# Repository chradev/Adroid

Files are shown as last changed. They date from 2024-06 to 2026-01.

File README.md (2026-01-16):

## Adroid

<a href="https://github.com/chradev/Adroid" target="_blank">Adroid</a> is proposed as an open S.T.E.A.M. platform and a process for building educational aids like robots following the Open Source movement in all its aspects, including but not limited to the ideas, algorithms, internal and external design, mechanical, electronic, and software staff. It is intended to include latest science, technology, and art achievements with a special respect to ***"Do it by mind, heart, and hands; learn by doing and teach by learning!"*** principles or simply ***"Learn by Doing!"***, appropriate for any person's age, interests, and profession.

Adroid robots ­ the Small, the Tall, the Wide, the Smart Малкият, Високият, Широкият, Умният (Дребосъкът, Дангалакът, Дебелакът, Добрякът)

#### <p align=center>Adroid the project, is all about "Do it by mind, heart, and hands; learn by doing and teach by learning!"<br>whose mission is to perfect your brain and hands using the latest science, technology, and art achievements.</p>

Adroid is not only a platform but it is also a continuous process intended to accumulate all gained knowledge and experience by all participants in S.T.E.A.M. the educational processes using it. A special relational multi-dimensional knowledge base and tools will be created and updated continuously to help the learning and teaching processes. On the other hand Adroid can be used by artists, scientists and engineers to reach better results faster.

## Learn by Doing!

Open S.T.E.A.M. is an idea directly related to a platform for multidisciplinary projects, the scope of which is the best possible learning process through the active participation of the parties in their implementation. In this line of thought, the parties to whom the process is directed are equal in terms of rights and obligations, often changing their roles as students and teachers.

Therefore, the following topics are outlined in the Adroid project as a beginning:

* Development of AI-based open S.T.E.A.M. process and comprehensive toolkit to learn and teach by doing;
* Stereo and panoramic robot vision, including AI-based object detection, recognition and following;
* Speech synthesis and recognition for human-like communicating robots, optionally based on AI;
* Emotional behavior through animation on the built-in robot display optionally based on AI;
* Active Ball Joint Mechanism incl. 3D absolute positioning system for head movement;
* Distributed, multi-process/-core/-thread control system based on uROS and ROS 2;
* Advanced stereo and panoramic system for streaming with low latency and ePTZ;
* Body transformation based on a set of strength and positioning sensors;
* Development of liquid multi-color jet system for painting robots;
* Following the latest achievements in the sciences and technologies, etc.

The above list will be updated continuously, so any new ideas are welcome.

## How easy is it to use AI?

#### It is easy to use Raspberry Pi AI Kit (HAILO 8L - 13 TOPS) on Raspberry Pi 5!

Some tests were made to use the Raspberry Pi AI Kit (HAILO 8L - 13 TOPS) on Raspberry Pi 5 16GB with Debian 13 (Trixie) desktop distribution and Linux kernel ver. 6.12.47. AI Kit's M.2 module and 512GB NVMe SSD were mounted on WaveShare PCIe to 2-CHANNEL M.2 HAT+ for Raspberry Pi 5. Arducam 16MP IMX519 autofocus camera was connected to the first CSI interface, and appropriate software (libcamera2, OpenCV etc.) was installed and tested to work. A series of performance tests were also made, and a better Geekbench CPU score was found for Raspberry Pi 5 Model B Rev 1.1 vs. Rev 1.0 (<a href="https://browser.geekbench.com/v6/cpu/15497913" target="_blank">2091/891</a> vs. <a href="https://browser.geekbench.com/v6/cpu/5636316" target="_blank">1629/793</a>).

Appropriate software and AI demo examples for the Raspberry Pi AI Kit (HAILO 8L - 13 TOPS) are installed and tested to work. The camera was directed to the high-resolution monitor of the desktop computer, where the following YouTube video clips were displayed:

* <a href="https://www.youtube.com/watch?v=w_agSeXwxhU" target="_blank">Kara Swisher's discussion with Nobel laureate Geoffrey Hinton, known as one of the “godfathers of AI” for his work</a>,
* <a href="https://www.youtube.com/watch?v=VX-Vx-aLdHg" target="_blank">National Folklore Festival for amateurs "U bre, de bre", Varna, Bulgaria, 2013 - doubles competition, second round</a>.

<table style="width: 100%; height: 100%; margins: 0; padding: 0;">
  <tr style="margins: 0; padding: 0;">
    <td style="width: 20%; height: 100%; margins: 0; padding: 0;">
      </td>
    <td style="width: 20%; height: 100%; margins: 0; padding: 0;">
      </td>
    <td style="width: 30%; height: 100%; margins: 0; padding: 0;">
      </td>
    <td style="width: 30%; height: 100%; margins: 0; padding: 0;">
      </td>
  </tr>
</table>

It is worth noting that when using the Raspberry Pi AI Kit (HAILO 8L - 13 TOPS), the CPU load (16% total and 11.5% for the AI application) and memory usage (1.34 GB total and 233 MB for the AI application) of the Raspberry Pi 5 are negligible. On the other hand, video captured by the Arducam 16MP IMX519 autofocus camera was processed by the Raspberry Pi AI Kit (HAILO 8L - 13 TOPS) with the same frame rate and with a lot of objects analyzed.

#### It is easy to use Raspberry Pi AI Camera – IMX500 12MP on Raspberry Pi 5!

The Raspberry Pi 12MP AI Camera (IMX500) module was installed on the second CSI interface of the same Raspberry Pi 5 16GB, appropriate configuration was set and it was tested to work. After installing of required software AI functionality was tested with the above mentioned video clips.

<table style="width: 100%; height: 100%; margins: 0; padding: 0;">
  <tr style="margins: 0; padding: 0;">
    <td style="width: 19%; height: 100%; margins: 0; padding: 0;">
      </td>
    <td style="width: 15.4%; height: 100%; margins: 0; padding: 0;">
      </td>
    <td style="width: 24%; height: 100%; margins: 0; padding: 0;">
      </td>
    <td style="width: 24%; height: 100%; margins: 0; padding: 0;">
      </td>
  </tr>
</table>

#### AI solutions comparison

Later on both Raspberry Pi AI Camera – IMX500 12MP and Raspberry Pi AI Kit (HAILO 8L - 13 TOPS) with Arducam 16MP IMX519 autofocus camera were tested to work together on Raspberry Pi 5 16GB.

<table style="width: 100%; height: 100%; margins: 0; padding: 0;">
  <tr style="margins: 0; padding: 0;">
    <td style="width: 8.5%; height: 100%; margins: 0; padding: 0;">
      </td>
    <td style="width: 18%; height: 100%; margins: 0; padding: 0;">
      </td>
    <td style="width: 19.5%; height: 100%; margins: 0; padding: 0;">
      </td>
    <td style="width: 31%; height: 100%; margins: 0; padding: 0;">
      </td>
  </tr>
</table>

Measured total CPU load was 26% (2.5% and 10.4%, respectively), and total memory usage was 10% or 1.58 GB (316 MB and 230 MB, respectively). As a result of comparison, it can be noted that the RPi AI camera solution is 30% cheaper (84.36 € vs. 85.90 € + 33.75 €) and uses fewer CPU resources (2.5% vs. 10%), but using a standard RPi camera with a HAILO 8L AI accelerator is a more powerful and unified solution. Moreover, the use of dedicated AI processing units will allow for easier migration to other, much more powerful platforms.

#### HAILO AI development software

<a href="https://hailo.ai/" target=_blank>Hailo AI</a> development software and examples were installed on Raspberry Pi 5 16GB with Seeed Studio's PCIe 3.0 to 2x M.2 hat and tested with Raspberry Pi AI Kit (HAILO 8L - 13 TOPS) thanks to the following projects:

- <a href="https://github.com/hailo-ai/hailo-apps" target=_blank>Hailo Applications</a>
- <a href="https://github.com/hailo-ai/hailo-rpi5-examples" target=_blank>Hailo Raspberry Pi 5 Examples</a>

After fixing the installation problem by changing the `HAILORT_PACKAGE_NAME_RPI` global variable in <a href="https://github.com/hailo-ai/hailo-apps/blob/main/hailo_apps/python/core/common/defines.py#L15" target=_blank>defines.py</a> to `hailort` all staff started working fine, and the following results were observed:

<table style="width: 100%; height: 100%; margins: 0; padding: 0;">
  <tr style="margins: 0; padding: 0;">
    <td style="width: 33.3%; text-align: center; margins: 0; padding: 0;">
      <p>Object detection: hailo-detect-simple</p></td>
    <td style="width: 33.3%; text-align: center; margins: 0; padding: 0;">
      <p>Pose estimation: hailo-pose</p></td>
    <td style="width: 33.3%; text-align: center; margins: 0; padding: 0;">
      <p>Instance segmentation: hailo-seg</p></td>
  </tr>
  <tr style="margins: 0; padding: 0;">
    <td style="text-align: center; margins: 0; padding: 0;">
      </td>
    <td style="text-align: center; margins: 0; padding: 0;">
      </td>
    <td style="text-align: center; margins: 0; padding: 0;">
      </td>
  </tr>
</table>

**Notes:**

- Animated pictures are taken from <a href="https://github.com/hailo-ai/hailo-apps" target=_blank>Hailo Applications</a>. Thanks for sharing.
- Task charts are taken from <a href="https://hailo.ai/products/hailo-software/model-explorer-vision/" target=_blank>Hailo Model Explorer</a> for HAILO 8L AI processor, All Models, Original + Quantized and Batch size = 8;

#### Performance comparison table of tested AI solutions

It was chosen to test the Raspberry Pi 5 Model B with 16 GB and an adapter with 2x M.2 PCIe slots for connecting both the NVMe SSD disk and the HAILO 8L AI co-processor. There were two candidates with PCIe switches: Gen 2 from Waveshare and Gen 3 from Seed Studio. One of the limitations is that RPi 5 PCIe Gen 3 support is experimental, and some problems encountered at installation had to be overcome by adding `dtoverlay=pciex1-compat-pi5,no-mip` in `/boot/firmware/config.txt`. Linux commands like `hdparam` and `dd`, and <a href="https://github.com/Seeed-Projects/Benchmarking-YOLOv8-on-Raspberry-PI-reComputer-r1000-and-AIkit-Hailo-8L" target=_blank>performance tests developed by the Seeed Studio team</a> were used to measure NVMe SSD read/write speeds and HAILO 8L performance at processing object detection and pose estimation models. The results are summarized in the table below:



**Notes:**

- Using a PCIe Gen 3 switch is a must to increase:
 - the speeds of both write and buffered read operations for NVMe SSD disks,
 - performance of Hailo AI accelerator modules at video streams processing;
- Seeed Studio's PCIe 3.0 to 2x M.2 hat is a good choice because:
 - it doubles R/W speeds over PCIe to NVMe SSD and Hailo AI modules,
 - it keeps the GPIO header usable with its rear-mount design,
 - it doesn't matter where the two devices are plugged in;
- Unfortunately,
 - Gen 3 speeds is "out of spec" and officially unsupported by Raspberry Pi,
 - it has a problem with M.2 Interface Peripheral (MIP) compatibility on RPi 5, 
 - it is more expensive because of its over-functionality and lack of alternatives.

#### Benchmark of YOLOv8 AI models made by Seeed Studio team

YOLOv8 (You Only Look Once version 8) is the popular most YOLO series of real-time pose estimation and object detection models. It builds upon the strengths of its predecessors by introducing several advancements in speed, accuracy, and flexibility. The Raspberry AI kit, featuring a 13 TOPS neural network inference accelerator built around the Hailo-8L chip is used to accelerate inference speed of RPi 5 and CM4 boards. PCIe Gen 2 and Gen 3 speeds are used to measure performance. In addition main CPU and the NVIDIA Jetson Orin NX 16GB with built-in accelerator are also used to test the same demo. Results are published on:

* <a href="https://github.com/Seeed-Projects/Benchmarking-YOLOv8-on-Raspberry-PI-reComputer-r1000-and-AIkit-Hailo-8L" target="_blank">Github project: Benchmarking-YOLOv8-on-Raspberry-PI-reComputer-r1000-and-AIkit-Hailo-8L</a>,
* <a href="https://wiki.seeedstudio.com/benchmark_on_rpi5_and_cm4_running_yolov8s_with_rpi_ai_kit/" target="_blank">Seeed Studio wiki: Benchmark on RPi5 and CM4 running yolov8s with rpi ai kit </a>.

<table style="width: 100%; height: 100%; margins: 0; padding: 0;">
  <tr style="margins: 0; padding: 0;">
    <td style="width: 22%; height: 100%; margins: 0; padding: 0;">
      </td>
    <td style="width: 26%; height: 100%; margins: 0; padding: 0;">
      </td>
    <td style="width: 26%; height: 100%; margins: 0; padding: 0;">
      </td>
    <td style="width: 26%; height: 100%; margins: 0; padding: 0;">
      </td>
  </tr>
</table>

**Notes:**

- The acceleration effect of Hailo is noticeable;
- The frame rate of Pi5 under PCIe Gen3 is twice as high as under PCIe Gen2;
- The performance of CM4 after acceleration is unexpectedly good;
- The power consumption performance of Pi5 and CM4 is excellent when accelerated by Hailo8L.

#### Comparison table of AI solutions from different manufacturors



**Note:** The prices are taken from <a href="https://erelement.com/" target="_blank">Erelement Bg - Electronics and robotics</a>.

## Adroid robots comparison tables

#### Adroid robot variants

<table style="overflow-y: hidden; width: 100%;height: 100%;font-size:0.9em;text-align: center; border:1px; border-collapse: collapse;">
<thead>
<tr >
    <th width="10%" style="text-align: center;" > Adroid robot <br> variant / feature </th>
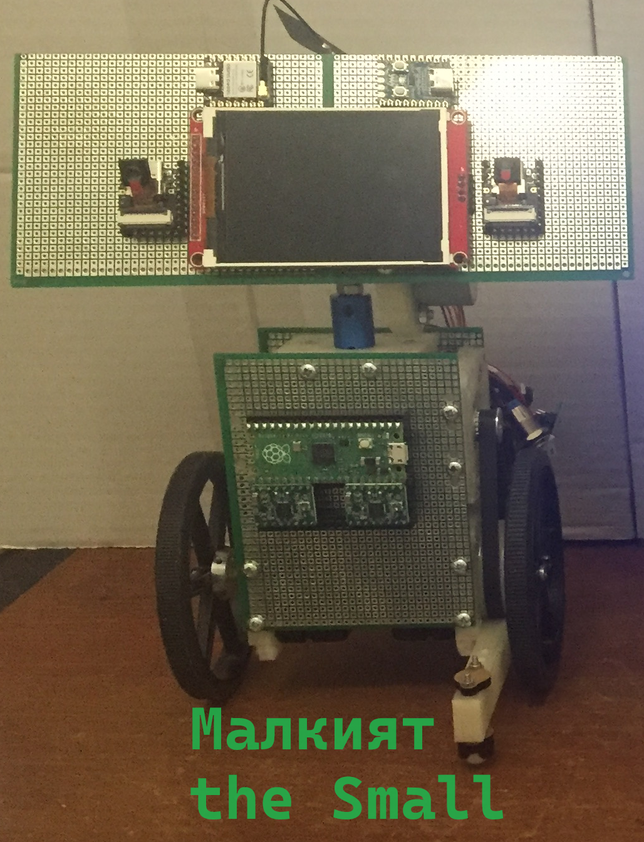
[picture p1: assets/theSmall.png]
    <th width="18%" style="text-align: center;"> </th>
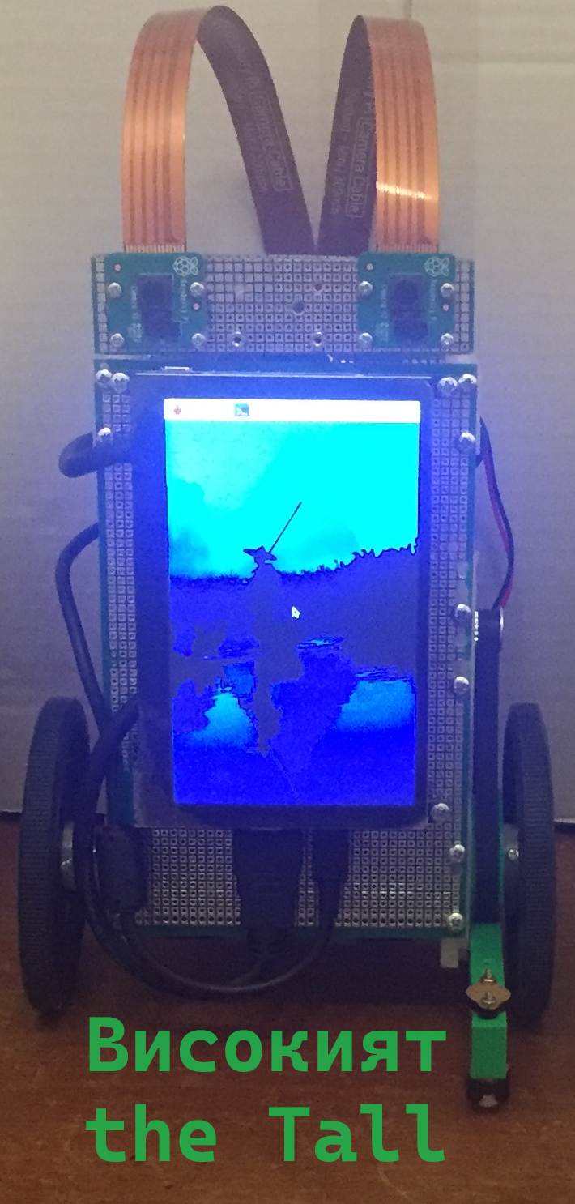
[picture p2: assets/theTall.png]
    <th width="18%" style="text-align: center;"> </th>
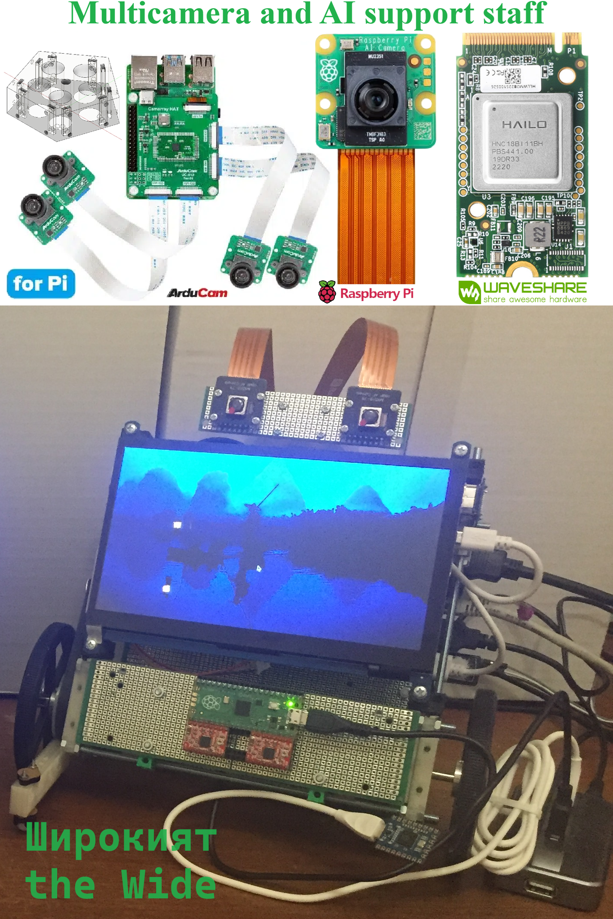
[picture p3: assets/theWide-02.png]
    <th width="18%" style="text-align: center;"> </th>
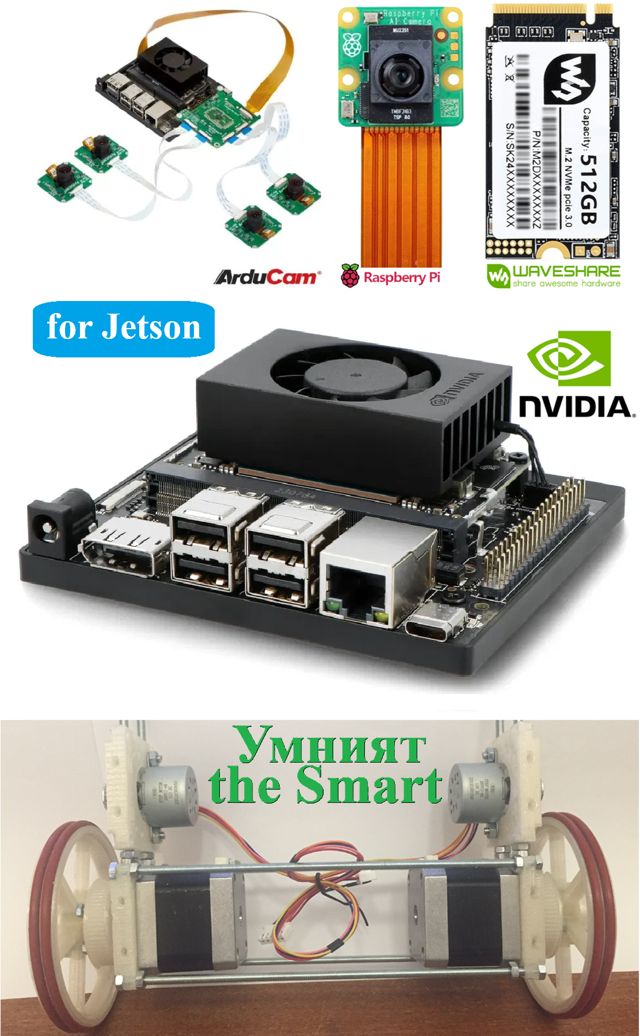
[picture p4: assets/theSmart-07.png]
    <th width="18%" style="text-align: center;"> </th></tr>
</thead><tbody>
<tr >
    <td style="text-align: end;"> Pricing </td>
    <td style="text-align: center;"> Low budget variant </td>
    <td style="text-align: center;" colspan="2" style="text-align: center;"> Advanced variants </td>
    <td style="text-align: center;">Variant with built-in AI acceleration</td></tr>
<tr style="background-color: #fcfccc;">
    <td style="text-align: end;" > Main computer hardware </td>
    <td style="text-align: center;" > Seeed Studio XIAO ESP32S3 Sense module </td>
    <td style="text-align: center;" colspan="2" > RPi 5 4/8/16GB RAM SBC, active cooling, Gen 2/3 PCIe to 2x M.2 hat, up to 2x NVMe SSD, Hailo 8/8L or other AI M.2 accelerator module (optional) </td>
    <td style="text-align: center;" >Nvidia Jetson Orin Nano Super Dev Kit, Gen 3 NVMe SSD</td></tr>
<tr >
    <td style="text-align: end;" > Main computer software </td>
    <td style="text-align: center;" > Free RTOS, C/C++ </td>
    <td style="text-align: center;" colspan="3" > Linux, C/C++, Python, JavaScript </td></tr>
<tr style="background-color: #fcfccc;">
    <td style="text-align: end;" > Dispaly devices </td>
    <td style="text-align: center;" > 3.2" TFT SPI or 4-5" TFT HDMI display and RPi Pico module </td>
    <td style="text-align: center;" colspan="2" > 5-7" TFT HDMI display or multimedia projector </td>
    <td style="text-align: center;" > 7" TFT DisplayPort display or multimedia projector </td></tr>
<tr >
    <td style="text-align: end;" > Auxiliary computer hardware </td>
    <td style="text-align: center;" colspan="4" > RPi Pico module </td></tr>
<tr style="background-color: #fcfccc;">
    <td style="text-align: end;" > Auxiliary computer software </td>
    <td style="text-align: center;" colspan="4" > C/C++, RPi Pico multicore and PIO features </td></tr>
<tr >
    <td style="text-align: end;" > Vision hardware </td>
    <td style="text-align: center;" > 1-2x Seeed Studio XIAO ESP32S3 Sense module with 2&nbsp;MP OV2640 SPI camera </td>
    <td style="text-align: center;" colspan="3" > 1-8x RPi or Arducam 8, 16 or 64 MP CSI cameras connected to RPi&nbsp;5 directly or via Arducam CamArray Hat, RPi AI cameras (optional) </td></tr>
<tr style="background-color: #fcfccc;">
    <td style="text-align: end;" > Vision software </td>
    <td style="text-align: center;" > Free RTOS, C/C++ and WS based MJPEG streaming </td>
    <td style="text-align: center;" colspan="3" > Linux, C/C++, Python, WS based h264 streaming server </td></tr>
<tr >
    <td style="text-align: end;" > Sound system </td>
    <td style="text-align: center;" > External sound card and built-in camera microphones </td>
    <td style="text-align: center;" colspan="2" > Speakers connected to HDMI display or I2S and microphones controlled by RPi 5 </td>
    <td style="text-align: center;" >I2S, sound amplifier and speakers</td></tr>
<tr style="background-color: #fcfccc;">
    <td style="text-align: end;" > Vision PTZ and head control </td>
    <td style="text-align: center;" >  Auxiliary computer with 1-2x geared stepper motors and position sensors </td>
    <td style="text-align: center;" colspan="3" > Auxiliary computer with 1-4x geared stepper motors, optional active ball joint mechanism, 3D position sensors and ePTZ based on camera control </td></tr>
<tr >
    <td style="text-align: end;" > Body slope control </td>
    <td style="text-align: center;" colspan="4" >  Auxiliary computer with 1-2x geared stepper motors and strength and position sensors </td></tr>
<tr style="background-color: #fcfccc;">
    <td style="text-align: end;" > Main movement control </td>
    <td style="text-align: center;" colspan="4" >  Auxiliary computer with 2x stepper motors and distance, line following, edge etc. sensors </td></tr>
<tr >
    <td style="text-align: end;" > Painting system </td>
    <td style="text-align: center;" > Single pen system </td>
    <td style="text-align: center;" colspan="3" > Multiple-pen or liquid multicolor jet system </td></tr>
<tr style="background-color: #fcfccc;">
    <td style="text-align: end;" > Power consumption </td>
    <td style="text-align: center;" > 10W max; 2S LiPo battery</td>
    <td style="text-align: center;" colspan="3" > 25W max; 3S LiPo battery</td></tr>
<tr style="background-color: #fcfccc;">
    <td style="text-align: end;" > Power control </td>
    <td style="text-align: center;" colspan="4" > Wireless charger and UPS like power control </td></tr>
</tbody></table>

#### Adroid robot main computer variants

<table style="overflow-y: hidden; width: 100%;font-size:0.9em;text-align: center; border:1px; border-collapse: collapse;">
<thead><tr >
<th width="10%" style="text-align: center;vertical-align: middle;" > Adroid robot <br> main computer <br> variant / feature </th>
<th width="18%" style="text-align: center;vertical-align: top;"> Seeed Studio XIAO ESP32S3 <br> (Multiply MCUs & FreeRTOS) <br>
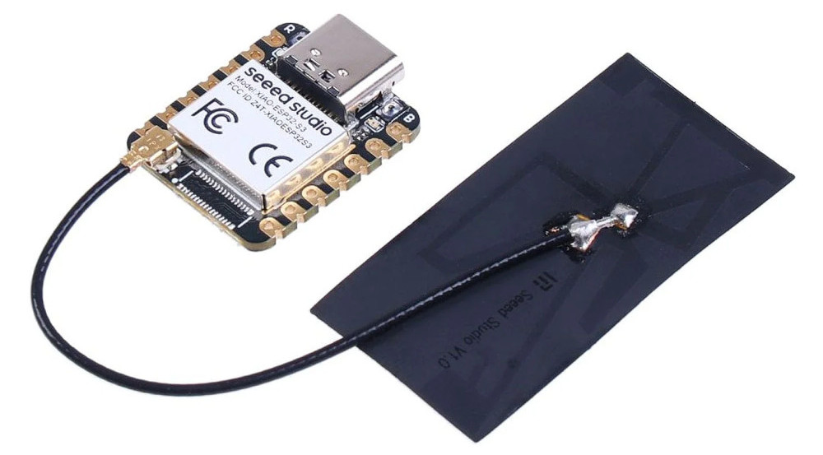
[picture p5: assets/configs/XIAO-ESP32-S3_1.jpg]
                                              <br> 
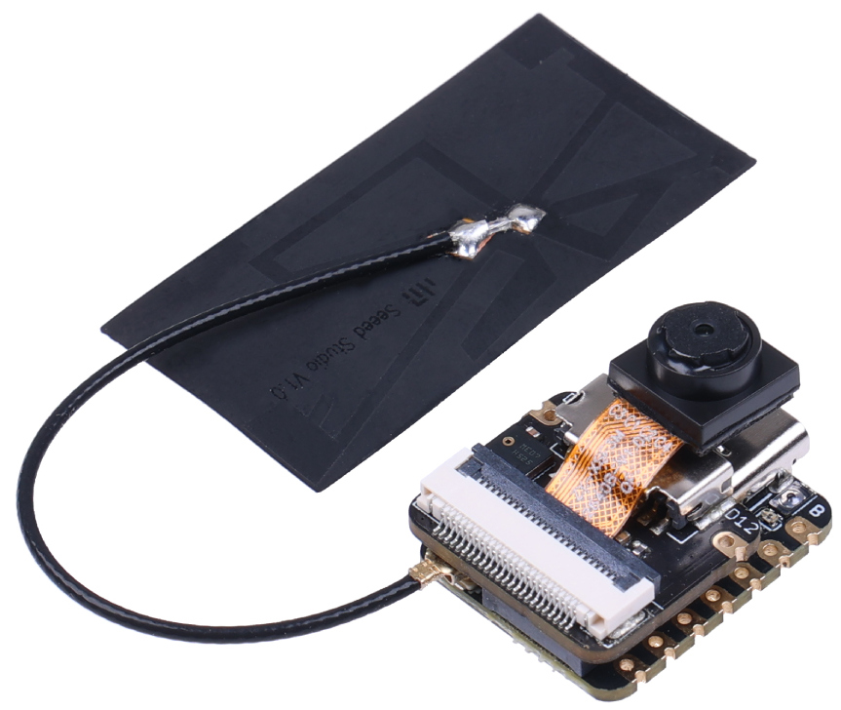
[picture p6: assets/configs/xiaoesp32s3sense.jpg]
                                              <br>
                                             2x Seeed Studio XIAO ESP32S3 Sense with OV2640 SPI camera and microphone<br> 
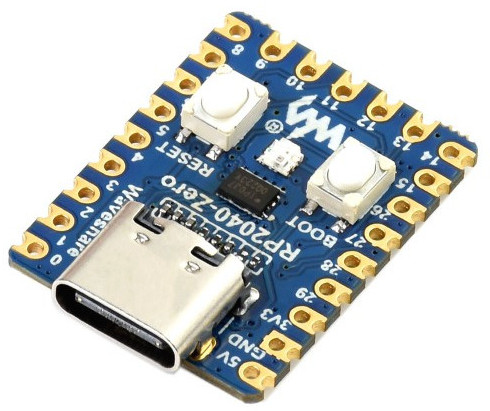
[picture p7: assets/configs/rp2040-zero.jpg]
                                             
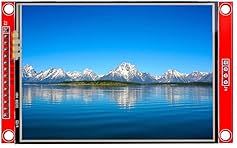
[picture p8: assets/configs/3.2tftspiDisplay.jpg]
                                              <br>
                                             RP2040-Zero and 3.2" TFT 320x240 SPI  built-in display (simple option)<br>
                                             
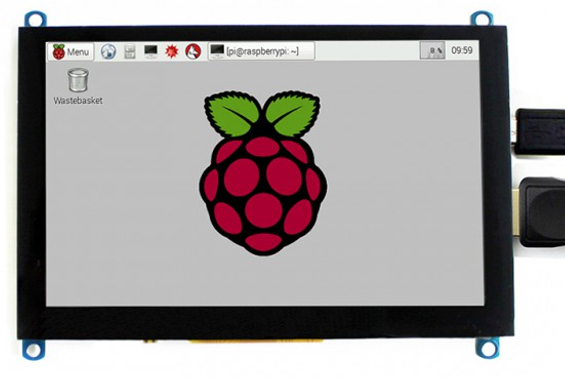
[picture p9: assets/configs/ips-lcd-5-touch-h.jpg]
                                              <br>
                                             RP2040-Zero and 5" TFT 800/480 HDMI  built-in display (advanced option)<br>
                                             </th>
<th width="18%" style="text-align: center;vertical-align: top;"> Raspberry Pi Zero 2 W <br> (Single SBC & Linux) <br>
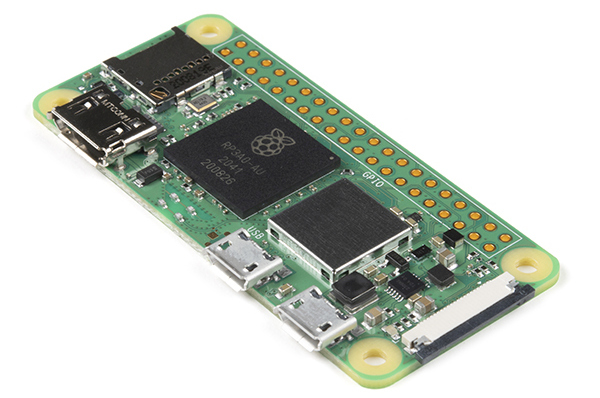
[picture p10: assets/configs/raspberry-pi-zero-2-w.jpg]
                                              <br> 
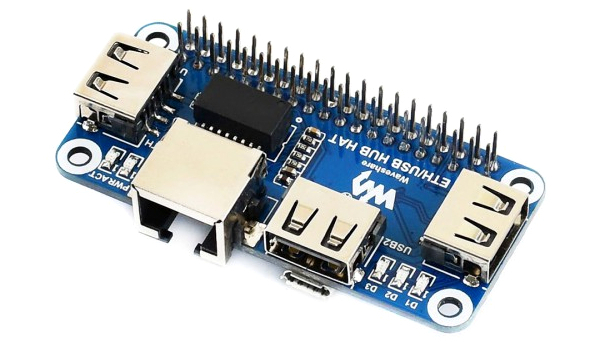
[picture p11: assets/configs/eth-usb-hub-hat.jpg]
                                             
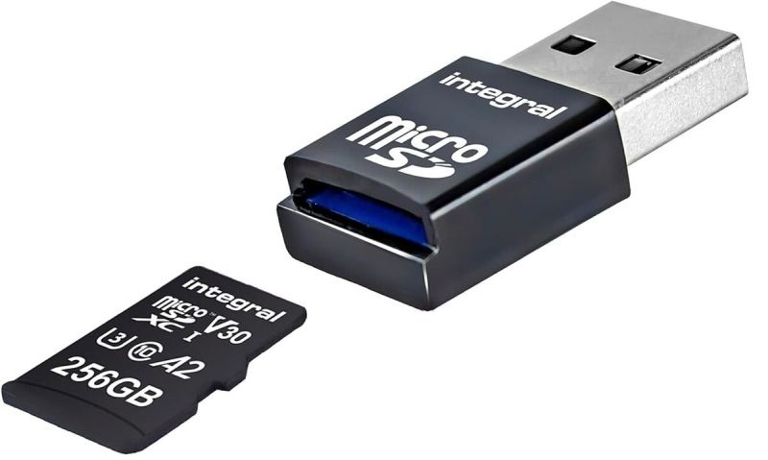
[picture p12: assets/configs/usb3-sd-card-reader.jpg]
                                               <br>
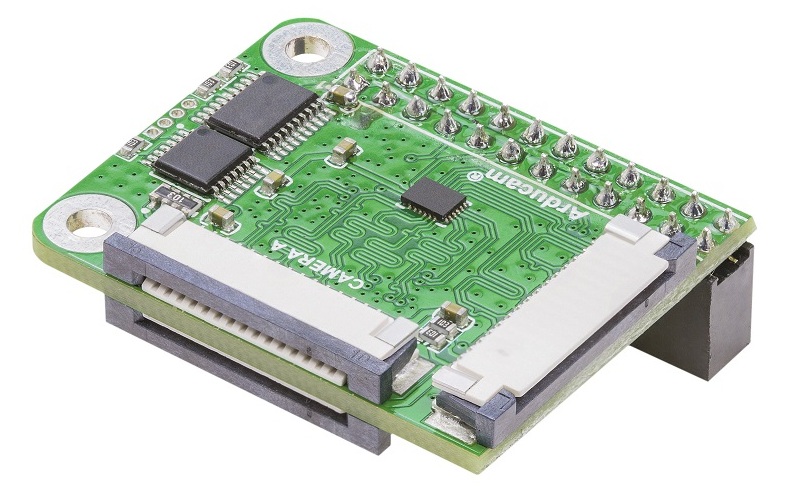
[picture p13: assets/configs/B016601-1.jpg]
                                              
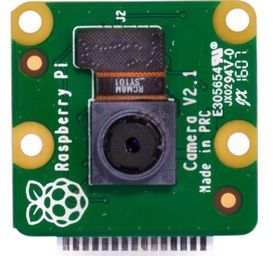
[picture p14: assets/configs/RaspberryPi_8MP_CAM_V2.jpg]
                                              <br>
                                             Stereo Camera Module V2 and 2x 5/8/12MP RPi cameras  (different options) <br>
                                             
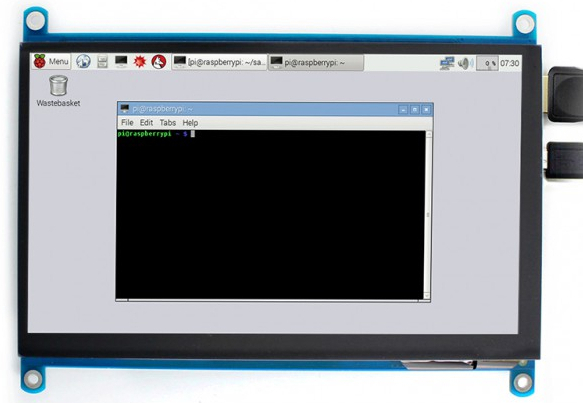
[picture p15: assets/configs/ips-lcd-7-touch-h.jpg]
                                              <br>
                                             5" / 7" HDMI built-in display (different options)
                                             </th>
<th width="18%" style="text-align: center;vertical-align: top;"> Raspberry Pi 5 4/8/16GB RAM <br> (Single SBC & Linux) <br>
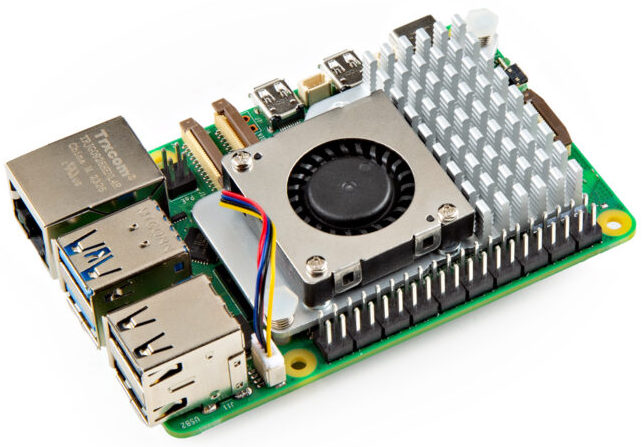
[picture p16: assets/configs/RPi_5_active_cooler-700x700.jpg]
                                              <br>
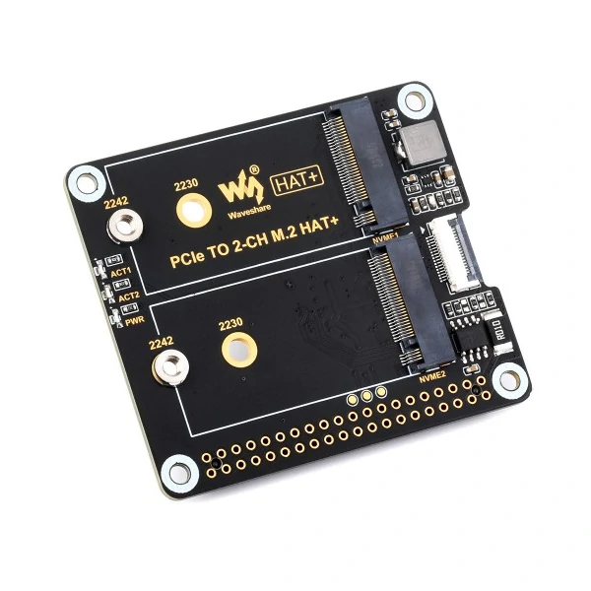
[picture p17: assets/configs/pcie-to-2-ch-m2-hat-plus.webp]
                                              
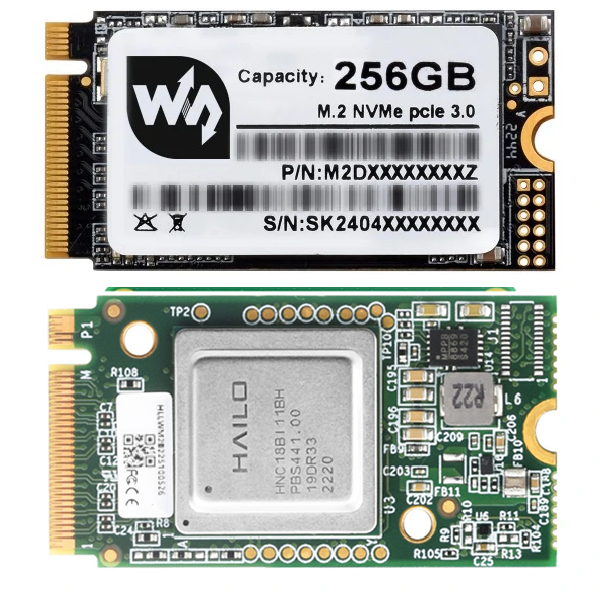
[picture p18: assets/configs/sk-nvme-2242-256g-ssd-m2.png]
                                              <br>
                                             Gen 2/3 PCIe to 2x M.2 hat with NVMe SSD and AI accelerator <br>
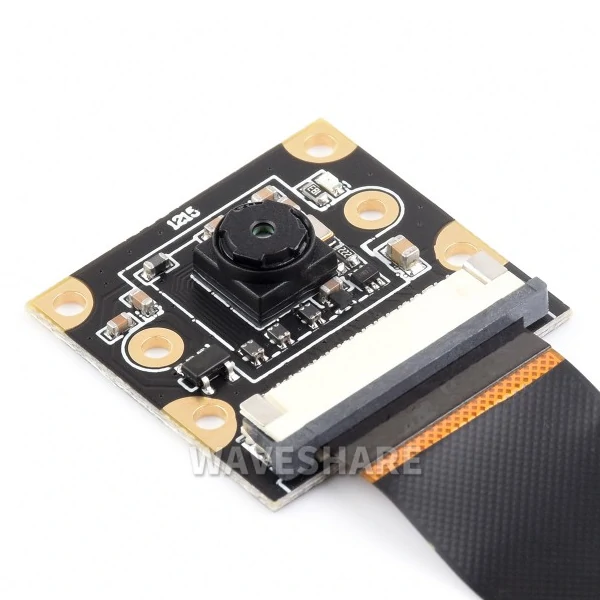
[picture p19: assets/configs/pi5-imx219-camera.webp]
                                             
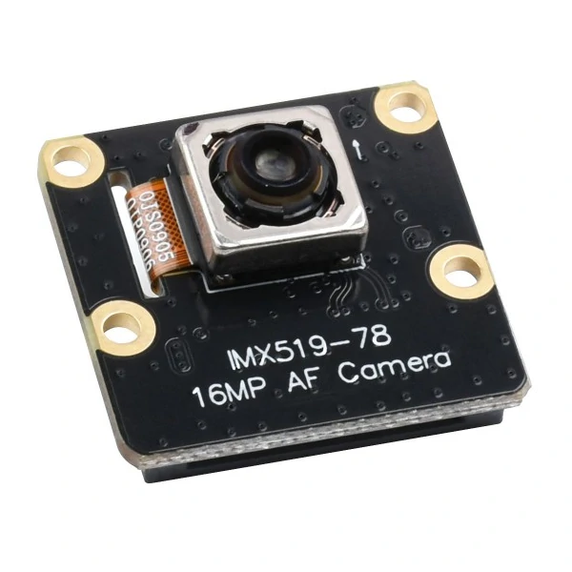
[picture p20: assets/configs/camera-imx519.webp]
                                             
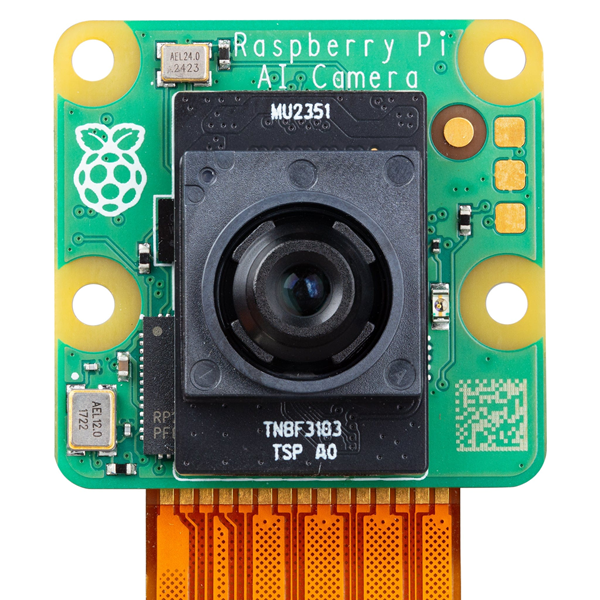
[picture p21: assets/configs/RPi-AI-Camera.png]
                                              <br>
                                             up to 2x RPi 8/16/64MP or AI cammeras (different options) <br>
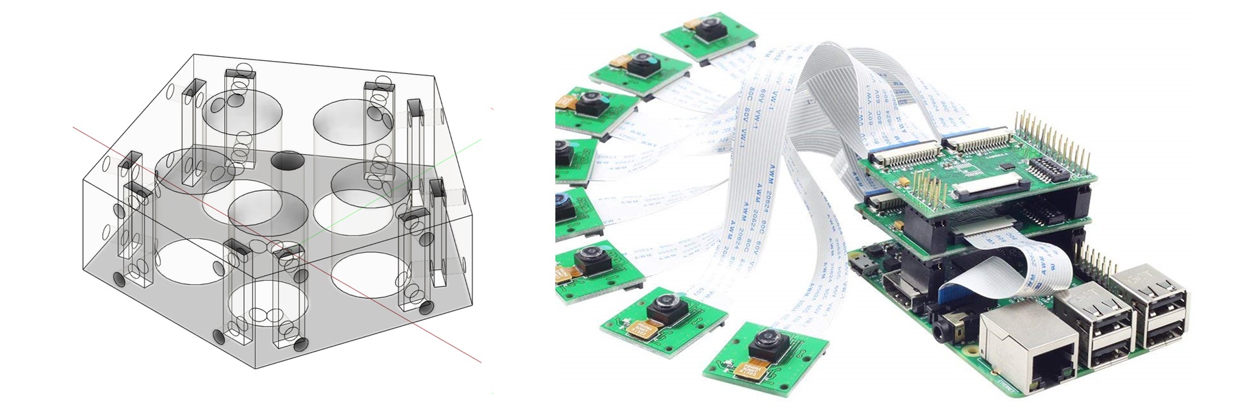
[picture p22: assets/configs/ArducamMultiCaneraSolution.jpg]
                                              <br>
                                             up to 2x Synchronized Quad-Camera hats with up to 8 cammeras <br>
                                             
                                              <br>
                                             5" / 7" HDMI built-in display (different options) <br>
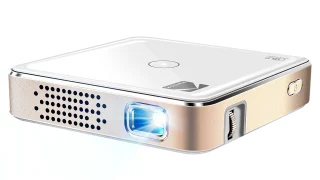
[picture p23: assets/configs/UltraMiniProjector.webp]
                                             
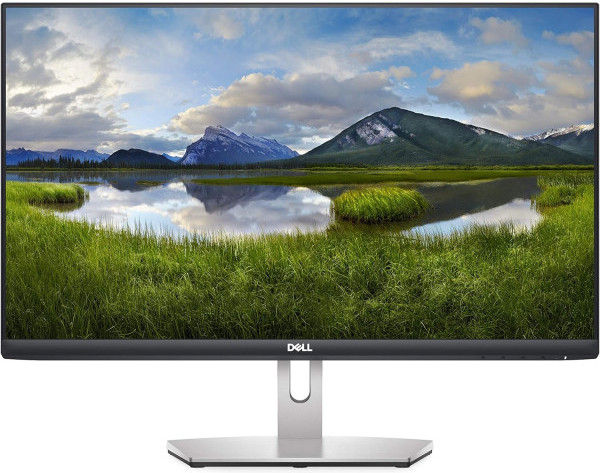
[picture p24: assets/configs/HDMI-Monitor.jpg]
                                              <br>
                                             Pico Projector or Desktop Monitor (not includded)
                                            </th>
<th width="18%" style="text-align: center;vertical-align: top;"> Nvidia Jetson Orin Nano Super Dev Kit <br> (SOM & Carrier board & NVMe SSD & Linux) <br>
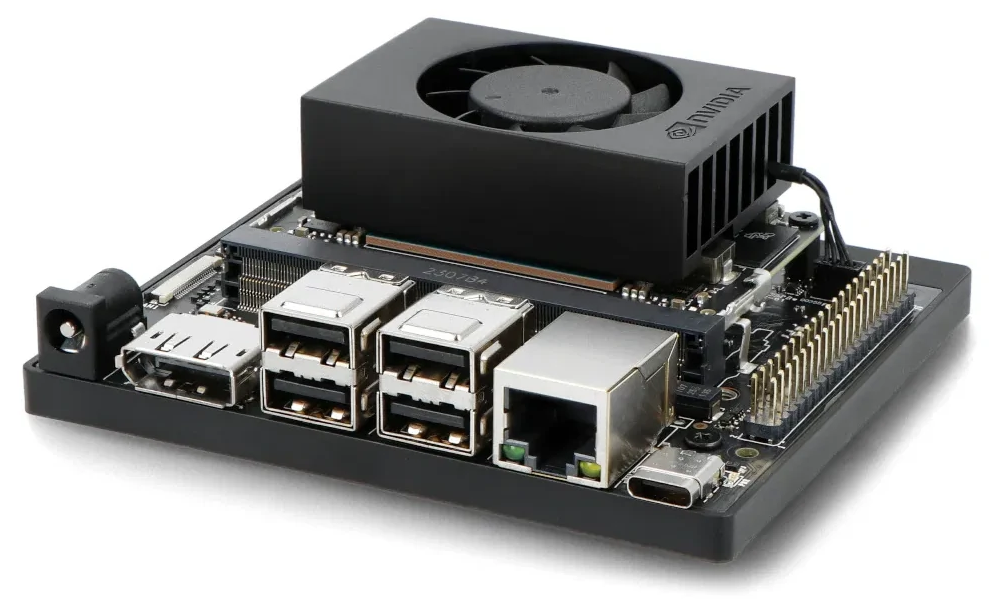
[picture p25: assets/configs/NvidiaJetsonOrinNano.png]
                                              <br>
                                             
                                             
                                              <br>
                                             up to 2x RPi 8/16/64MP or AI cammeras (different options) <br>
                                              <br>
                                             up to 2x Synchronized Quad-Camera hats with up to 8 cammeras <br>
                                             
                                              <br>
                                             5" / 7" HDMI built-in display (different options) <br>
                                             
                                              <br>
                                             Pico Projector or Desktop Monitor (not includded)
                                            </th>
</tr></thead><tbody>
<tr >
    <td style="text-align: end;"> Pricing </td>
    <td style="text-align: center;"> Low budget variant </td>
    <td style="text-align: center;"> Middle budget variant </td>
    <td colspan="2" style="text-align: center;"> Highly priced variant </td></tr>
<tr style="background-color: #fcfccc;">
    <td style="text-align: end;"> Rough BOM <br> [incl. VAT] </td>
    <td style="text-align: center;"> 100 &euro; </td>
    <td style="text-align: center;"> 225 &euro; (with 2x 8MP cameras and 5" display) </td>
    <td style="text-align: center;"> 350 &euro; (with 8GB RAM, 512 GB NVMe SSD, 2x 16MP cameras and 7" display)<br>+200 &euro; (add 3x 16MP cameras, Camarray Hat and Hailo 8L 13 TOPS AI accelerator) </td>
    <td style="text-align: center;"> 520 &euro; (Jetson Orin Nano Super with 512 GB NVMe SSD, 2x 16MP cameras and 7" display)<br>+130 &euro; (add 3x 16MP cameras and Camarray Hat) </td></tr>
<tr >
    <td style="text-align: end;vertical-align: top;"> Base features </td>
    <td style="text-align: center;vertical-align: top;"> XIAO ESP32S3 Module, ESP32-S3R8 MCU with 240 MHz Xtensa LX7 dual-core, 32-bit CPU, 8MB PSRAM, 8MB Flash, 2,4 GHz Wi-Fi (802.11 B/G/N), Bluetooth 5 (LE) & Bluetooth Mesh, 3.7V LiPo battery charger (up to 100mA), USB native, UART, I2C, SPI, I2S, ADC, GPIOs, 2x modules XIAO ESP32S3 Sense with OV2640 camera and microphone, RP2040-Zero module and 3.2" TFT 320x240 SPI display </td>
    <td style="text-align: center;vertical-align: top;"> RPi Zero 2 W SBC, RP3A0 SoP (custom-built system-in-package with 1GHz quad-core 64-bit ARM Cortex-A53 CPU), 512MB of SDRAM, Wi-Fi 802.11.b/g/n, Bluetooth 4.2/BLE, I2C, SPI, UART, I2S, CSI, GPIOs, USB HUB / 100MB Ethernet HAT for Raspberry Pi Zero, SD card reader and fast SD card, Stereo Camera Module V2 and 2x 8MP RPi Camera V2, 5" 800x480 HDMI display with capacity USB Touch screen and audio output </td>
    <td style="text-align: center;vertical-align: top;"> RPi 5 4/8/16GB RAM SBC, Broadcom BCM2712 2.4GHz quad-core 64-bit Arm Cortex-A76 CPU, with Cryptographic Extension, 512KB per-core L2 caches, and a 2MB shared L3 cache, VideoCore VII GPU, supporting OpenGL ES 3.1, Vulkan 1.2, Dual 4Kp60 HDMI display output with HDR support, 4Kp60 HEVC decoder, 8GB LPDDR4X-4267 SDRAM, Dual-band 802.11ac Wi-Fi, Bluetooth 5.0 / Bluetooth Low Energy (BLE),  microSD card slot, with support for high-speed SDR104 mode, 2x USB 3.0 ports, supporting simultaneous 5Gbps operation, 2x USB 2.0 ports,  Gigabit Ethernet, 2x micro-HDMI ports supporting 4kp60 with HDR, 2x 4-lane MIPI camera/display transceivers,  PCIe 2.0 x1 interface for fast peripherals, PCIe to 2-CHANNEL M.2 HAT for RPi 5, 256GB M.2 NVME 2242 high-speed SSD with high-quality 3D TLC flash memory, I2C, SPI, UART, I2S, GPIOs, RPi 5 Active Cooler, 2x 16MP RPi IMX519 Camera with autofocus, 7" 1024x600 IPS HDMI display with capacity USB Touch screen and audio output </td>
    <td style="text-align: center;vertical-align: top;">Jetson Orin Nano 8GB System-On-Module (SOM): AI Performance: 67 INT8 TOPS; GPU: NVIDIA Ampere architecture with 1024 CUDA cores and 32 tensor cores; CPU: 6-core Arm® Cortex®-A78AE v8.2 64-bit CPU 1.5MB L2 + 4MB L3; RAM: 8GB 128-bit LPDDR5 102GB/s; Support for external NVMe; Power: 7 W – 25 W<br>Carrier Board: 4 x USB 3.2 Gen2 Type-A; 1 x USB-C; 1 x Gigabit Ethernet; Video output: DisplayPort 1.2 (no HDMI port); 2 x MIPI CSI connectors for cameras; 40-pin GPIO connector (I2C, SPI, UART, PWM и др.); M.2 Key M slot for NVMe SSD (no NVME modul); M.2 Key E slot for Wi-Fi / Bluetooth module (WiFi modul mounted); microSD slot for microSD card; DC power jack</td></tr>
<tr style="background-color: #fcfccc;">
    <td style="text-align: end;"> Dimensions </td>
    <td style="text-align: center;"> 21 x 17,5 mm </td>
    <td style="text-align: center;"> 65 x 30 mm </td>
    <td style="text-align: center;"> 85 x 56 mm </td>
    <td style="text-align: center;"> 91 x 103 mm </td></tr>
</tbody></table>

#### Adroid robot commom staff

<table style="overflow-y: hidden; width: 100%;font-size:0.9em;text-align: center; border:1px; border-collapse: collapse;">
<thead><tr >
<th width="43%" style="text-align: center;vertical-align: top;"> Powering system <br><br>
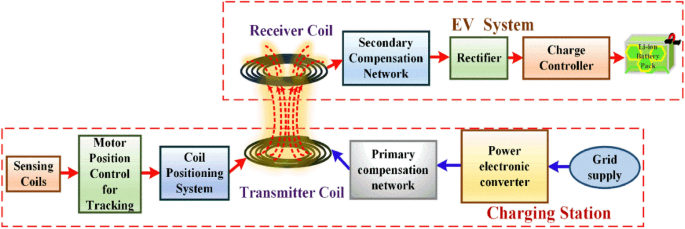
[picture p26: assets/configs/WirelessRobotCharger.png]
                                              <br>
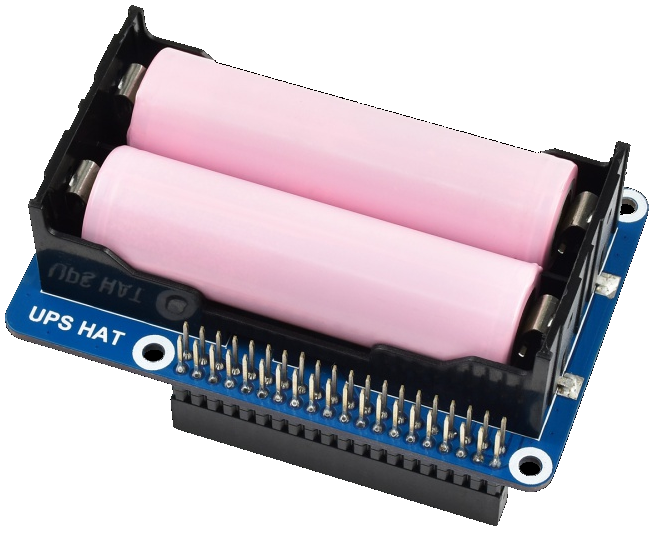
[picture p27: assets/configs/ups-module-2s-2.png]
                                             
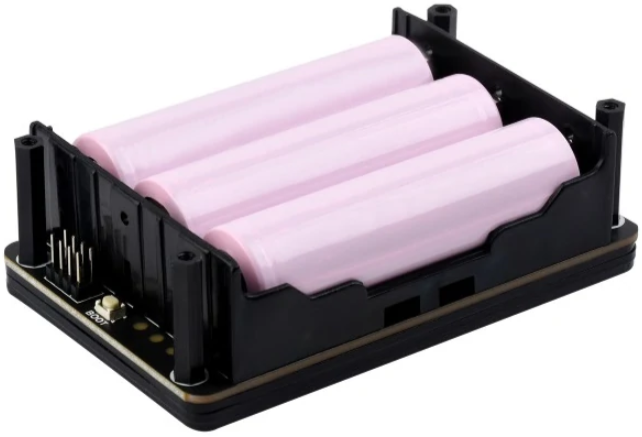
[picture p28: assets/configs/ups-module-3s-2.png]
                                             
                                             </th>
<th width="27%" style="text-align: center;vertical-align: top;"> Main movement system <br><br>
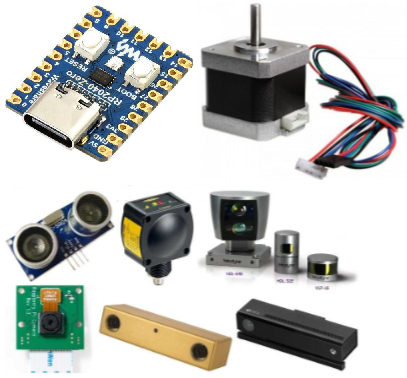
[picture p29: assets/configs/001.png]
                                              <br>
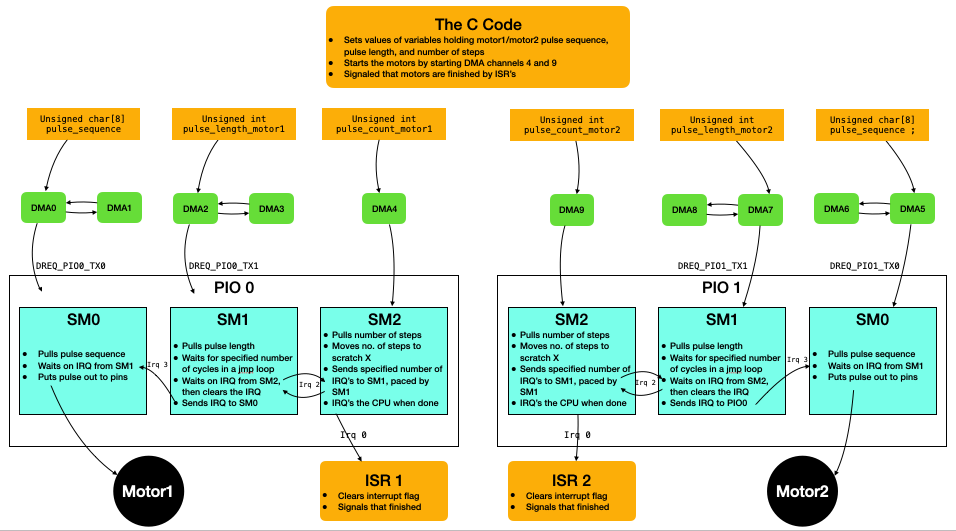
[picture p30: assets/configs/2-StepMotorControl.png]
                                             
                                             </th>
<th width="30%" style="text-align: center;vertical-align: top;"> Auxiliary movement systems <br><br>
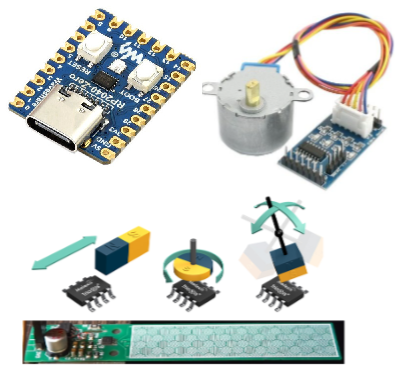
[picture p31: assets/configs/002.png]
                                              <br>
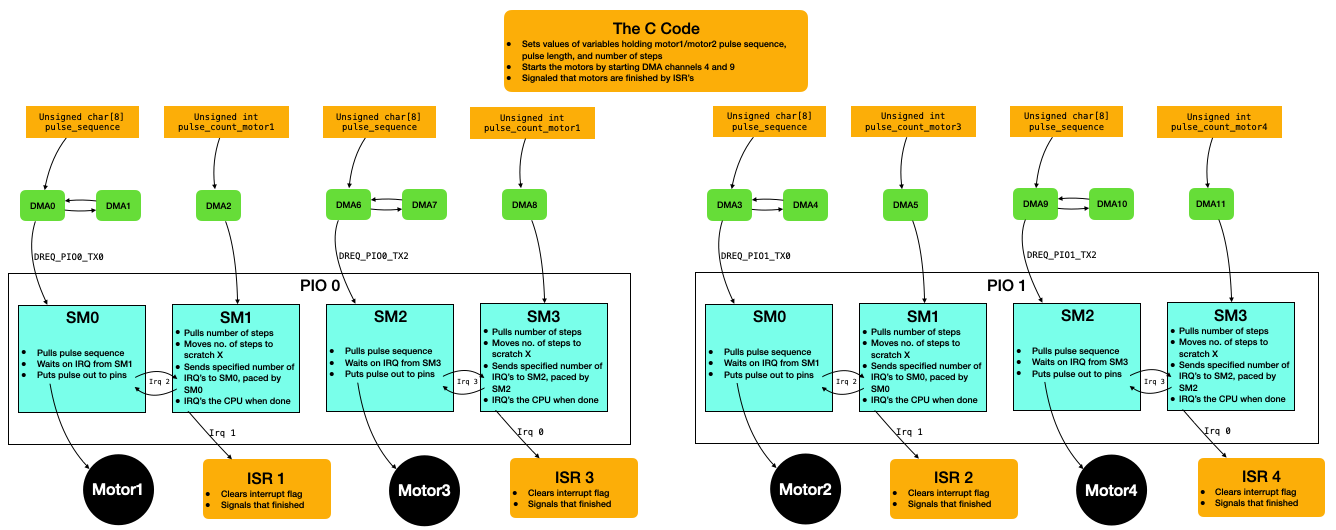
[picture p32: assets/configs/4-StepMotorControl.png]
                                             
                                             </th>
</tr><tr>
<td>
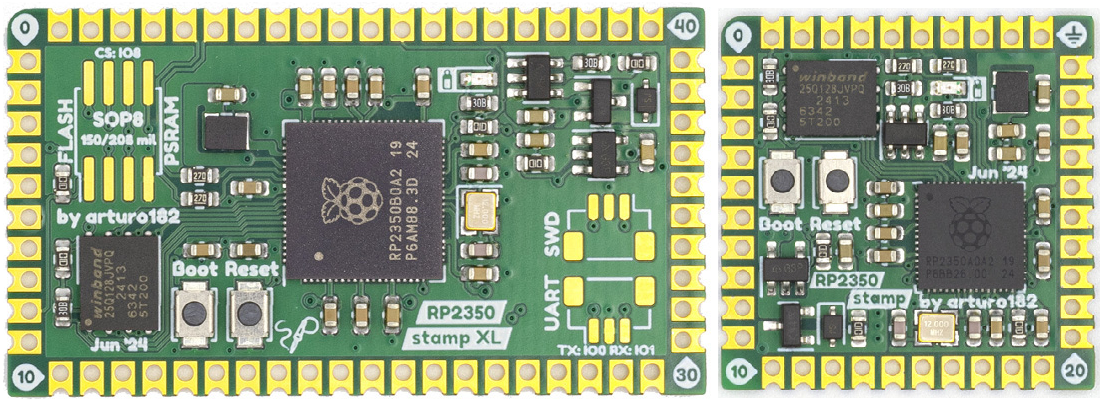
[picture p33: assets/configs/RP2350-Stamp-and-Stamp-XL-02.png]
    
</td>
<td colspan="2" style="vertical-align: middle;">
The new RP2350 series of MCUs from Raspberry is now available, and migrations from previous MCUs like RP2040 is an option for Adroid robot common staff.
<br><br>
Significant advantages in the new generation of MCUs are:
<ul>
  <li>dual-core architecture with 150MHz Cortex-M33 or Hazard3 RISC-V cores;</li>
  <li>bigger internal RAM (520KB of SRAM) and 2 MB internal flash (in RP2354);</li>
  <li>up to 16 MB of external QSPI flash/PSRAM via dedicated QSPI bus;</li>
  <li>a special High Speed Transmit (HSTX) peripheral that drives 4 lanes of differential data transmission to DVI output;</li>
  <li>12x PIO state machines - 3x PIO blocks with 4 state machines each;</li>
  <li>more GPIOs (up to 48 in QFN-80 package), peripherals, security options etc.</li>
</ul>
</td>
</tr></thead></table>

#### <p style="text-align: right;">Comparison table of direct drive motor candidates from different suppliers</p>



#### <p style="text-align: right;">Comparison table of geared motor candidates from different suppliers</p>



**Note:** The prices and product details are taken from the websites of the referred suppliers.

#### Brushless direct drive PMSM servo motors as the best candidates for the robot's driving wheels and joints

**Google AI:** Direct Drive PMSM Brushless Servo Motors combine the high efficiency and torque of Permanent Magnet Synchronous Motors (PMSM) with direct connection to the load, eliminating gears for precise, backlash-free motion, high reliability, and compact designs, ideal for robotics and automation needing high accuracy, fast response, and high torque at lower speeds, often featuring integrated encoders and controllers for all-in-one solutions. 

Waveshare's series of Direct Drive Servo Motors (DDSM) are all-in-one solutions based on the integrated development concept, featuring a high-reliability PMSM brushless motor with an outer rotor integrated with an encoder and servo.

<table style="border: none; width: 100%; height: 100%; margins: 0; padding: 0;">
  <tr style="border: none; margins: 0; padding: 0;">
    <td style="border: none; width: 50%; height: 100%; margins: 0; padding-right: 20; background-color: white;">
All motors in the series feature:
<br><br>

<ul>
  <li>Ultra low noise; High precision and zero-backlash</li>
  <li>Fast response, direct drive without delay</li>
  <li>Integrated motor and driver, compact structure and high integration</li>
  <li>Supports multiply bus communication like LIN, UART and RS485</li>
  <li>Feedback information through communication such as position, speed, current, error code, etc.</li>
  <li>With Hall position detection, over-current protection, etc.</li>
  <li>Supports electric brake</li>
  <li>No drive mechanical friction, drive efficiency close to 99.99%</li>
</ul>

<br>
Their multiple operating modes (like current, position, and velocity loop modes) allow to control:
<br><br>

<ul>
  <li>motor output power by controlling the current,</li>
  <li>the angle of the hub motor in the range of 0-360° in position loop mode,</li>
  <li>and the rotational speed in velocity loop mode.</li>
</ul>
    </td>
    <td style="border: none; width: 50%; height: 100%; margins: 0; padding: 0; background-color: white;">
        
    </td>
  </tr>
</table>

#### <p style="text-align: right;">Selection Table of Direct Drive PMSM (Permanent Magnet Synchronous Motors) Brushless Servo Motors from <a href="https://www.waveshare.com/" target=_blank>Waveshare</a></p>

| Model | Price | Size | No-load speed | Rated speed | Rated torque | Locked torque | Rated voltage | Operating voltage | Interface | Weight | Main feature and operating modes |
| ----- | ----- | ---- | --- | --- | --- | --- | --- | --- | --- | -----  | ---  |
| <a href="https://www.waveshare.com/product/robotics/motors-servos/motors/ddsm210.htm" target=_blank>DDSM210</a> | $23.99 | &#8960;74 x 20  | 210±15rpm (0.91m/s) | 98rpm  | 0.25Nm | 0.85Nm | 14.4Vdc (4S LiPo) | 11V~22Vdc | UART  | 260g | Low Speed and High Torque;<br>Position and velocity loop modes |
| <a href="https://www.waveshare.com/product/robotics/motors-servos/motors/ddsm115.htm" target=_blank>DDSM115</a> | $64.99 | &#8960;100 x 43 | 200±10rpm (1.05m/s) | 115rpm | 0.96Nm | 2.0Nm  | 18Vdc (5S LiPo) | 12V~24Vdc | RS485 | 765±15g | Low Speed and High Torque;<br>Current, position and velocity loop modes |
| <a href="https://www.waveshare.com/product/robotics/motors-servos/motors/ddsm315.htm" target=_blank>DDSM315</a> | $49.99 | &#8960;78 x 32  | 315±10rpm (1.29m/s) | 200rpm | 0.55Nm | 1.1Nm  | 18Vdc (5S LiPo) | 12V~24Vdc | RS485 | 349±5g  | Wide Speed Range Adjustable;<br>Current, position and velocity loop modes |
| <a href="https://www.waveshare.com/product/robotics/motors-servos/motors/ddsm400.htm" target=_blank>DDSM400</a> | $25.99 | &#8960;74 x 20  | 400±20rpm (1.55m/s) | 100rpm | 0.15Nm | 0.3Nm  | 25.2Vdc (7S LiPo) | 9V~28Vdc  | LIN | 236g | Wide Speed Range Adjustable;<br>Current, position and velocity loop modes |

**Notes:**

- `Size` (wheel diameter and width) are rounded to the nearest whole number in mm;
- The `no-load speed` indicated in m/s is the maximal linear speed (without load);
- The average speed of normal human walking is 1.11 - 1.39 m/s (4-5 km/h).

## Leading principles and selection criteria

#### The core principle is ***OPENNESS***, as defined in the "Open Source" movement and expanded upon later:

The "open source way" is based on key principles of open exchange, collaborative participation, rapid prototyping, transparency, meritocracy, and community-oriented development. In the beginning, the "open source" referred to computer programs in which the source code is available to the general public for use or modification of the original design. Later on, this way of thinking spread to almost all aspects of human life and was also recognized by the businesses. Computer hardware, electronic, mechanical, etc. designs, the works of art, the musical compositions and their performances, and many others were also influenced. Finally, ***OPENNESS*** became the only real answer to the madness of globalization.

#### Another leading principles are:

* "Keep it as simple as possible" is essential for achieving the best results in the most effective way.
* Collaboration and communication are mandatory for the effective implementation of the training as the main goal.
* To work alone and as a teammate, to give and receive, to understand and explain at the same time, is essential in any case.
* Intensive use of the third-party expertise makes everyone a better expert, so use what others have already done to the maximum.
* The best way to constantly develop yourself is by using your own mind and hands to make improvements to what has already been achieved.

#### The selection of the hardware and software suitable for the project is based on the following criteria:

* Professional, technical and technological grade - the best products in their field are preferred.
* Accessibility, longevity, popularity and costs - the priority of the listed criteria is in descending order.
* Size and professionalism of the supporting community - a bigger and more responsive community of professionals is preferable.
* Openness and depth of the hardware and software support - open source software is a must, while it is good to have for the hardware.

Assessment of the products is based on a wide investigation, own tests and precise analysis. The test results are public and a subject of discussion. If significant flaws are discovered in the choice made, it will be subject to re-evaluation. When new products with better qualities appear, they can be recognized as alternative options.

#### List of the selected technologies and techniques for overall design and production:

* Laser-cut plastic materials, custom or prototyping PCBs for the supporting flat mechanical details and electronic components.
* 3D printing of unified mechanical details using appropriate materials like ABS, PLA, PETG, nylon, rubber, resin, etc.
* Manual drilling and screwing of the mechanical details and fastening with spacers of the electronic components.
* Using of bolts, screws, and nuts for joining all mechanical details and electronic components together.
* Soldering, crimping and interconnecting with cables and connectors of the electronic components.

In the development and testing phases, additional connections to external equipment such as power supplies, Ethernet hubs, Internet routers, monitors, keyboards, mice, etc. may be desired, which may require specific knowledge and skills. Some advanced skills like measuring with multimeter, oscilloscope, analyzer etc. may be needed when certain problems occur.

Laser-cut and 3D-printed details require 2D and 3D CAD/CAM design skills. The design and ordering for the fabrication of PCBs require specific knowledge and skills. For the production of the details with laser cutting and 3D printing, specific equipment and skills to work with it are required.

#### Software development - the art of the Computer Sciences

* Software design requires a wide set of theoretical knowledge and practical skills.
* Programming and testing require the ability to use a wide variety of software products and tools.
* The languages chosen for development and software implementation are C/C++, JavaScript, and Python.
* The operating systems chosen for development and software implementation are FreeRTOS for MCU and Linux for SBC.
* The main software architecture chosen is a distributed, multi-process/thread/core system based on uROS and ROS 2.
* The main communication technology chosen are web sockets and the publish-subscribe model. 

## Next steps to be done

#### Electrical and mechanical issues

* Schematic of motor drivers for driving wheels motors like auxiliary geared stepper motors;
* Unification of the motor control based on RPi Pico PIO algorithm by Van Hunter Adams;
* Modifying of 3D printed driving wheels to use both O-rings and silicone/rubber tires like in Pololu wheels;
* Unification of sets of motor pairs for driving wheels, head and body movement, including appropriate sensors;
* Adding of distance, line following and edge sensors to the driving wheels' setup;
* Adding of a pair of hall sensors for head movement for controlling of end and middle positions;
* Change from a single to a pair of auxiliary geared stepper motors for body movement (two-arm model);
* Migration from free wheel ball bearing to nylon pulley with bearing for arms;
* Adding of a pair of hall and PCB made strain gauge sensors for body movement by arms;
* Development of a PCB with arm sensors, electronics and geared stepper motors driver;
* Selecting an appropriate communication interface for both the RPi Pico MCUs and the RPi 5 board;
* Development and prototyping of appropriate printed circuits boards;
* Revising of chosen PRi 5 UPS power supply module;
* Investigation of the possibility to use a liquid based true color printing system.

#### Software issues

* Splitting of algorithms for deeply embedded applications for dual-core RPi Pico MCUs;
* Integration of uROS and ROS 2 systems into RPi Pico and RPi 5 firmware;
* Defining of appropriate configuration and command infrastructure;
* Implementation of appropriate control algorithms and information structure;
* Development of interactive user interface based Web Sockets ;
* Development of a task based interface for high level robot control.

## More new ideas

#### Adding some measurment features

Adding one more RPI Pico board, a multichannel <a href="https://github.com/gusmanb/logicanalyzer/tree/master" target="_blank">***100 Msps Logic Analyzer***</a> and/or <a href="https://github.com/fhdm-dev/scoppy" target="_blank">***500Ksps Digital Oscilloscope***</a> can be embedded in Adroid hardware. A better performance in measurement can be reached by using RPi Pico 2 or some other board with better analog features. Logic Analyzer can be enhanced by adding <a href="https://github.com/gusmanb/logicanalyzer/wiki/06---The-LogicAnalyzer-program#analyzing-protocols" target="_blank">protocol analyzers</a>. All these features can be used for both development and learning purposes. 

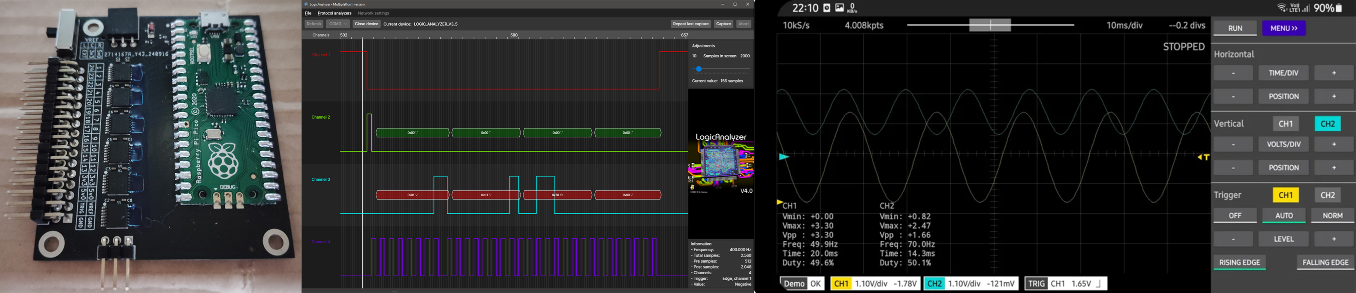
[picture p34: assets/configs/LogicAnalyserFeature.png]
RPi Pico Logic Analyzer


#### Use Active Ball Joint Mechanism for head movement

Using the idea of an active ball joint mechanism in combination with the motor control based on the RPi Pico PIO algorithm proposed by Van Hunter Adams will make head movement functionality extremely efficient.

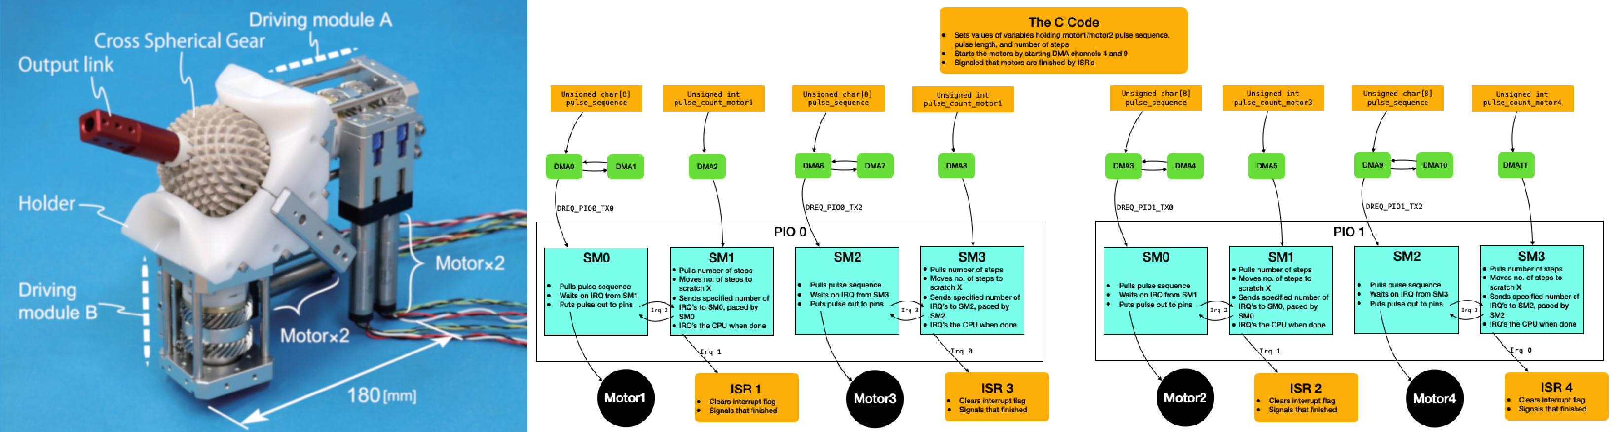
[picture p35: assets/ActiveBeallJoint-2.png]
Active Beall Joint Mechanism


The absolute positioning can be based on the measurement and the processing of the 3 spatial components of the magnetic flux density vector (i.e. BX, BY and BZ). Melexis has a long list of 2D and 3D sensing devices, like the one shown in the picture below.

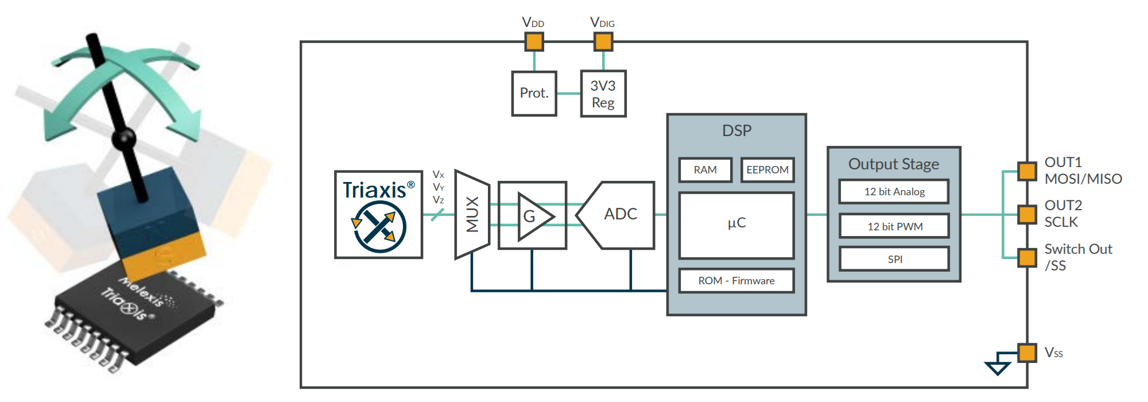
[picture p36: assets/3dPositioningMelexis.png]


#### Applying the Transformer's idea at body sloping

The ability to transform the robot from four-wheeled (2 driving and 2 auxiliary wheels) to two-wheeled balancing variant can be realized by adding auxiliary wheels to the robot arms. Some sensors, like an absolute positioning rotational sensor (360 degrees) and a strain gauge sensor to measure the reaction force, will help to enlarge precision of the body movement.

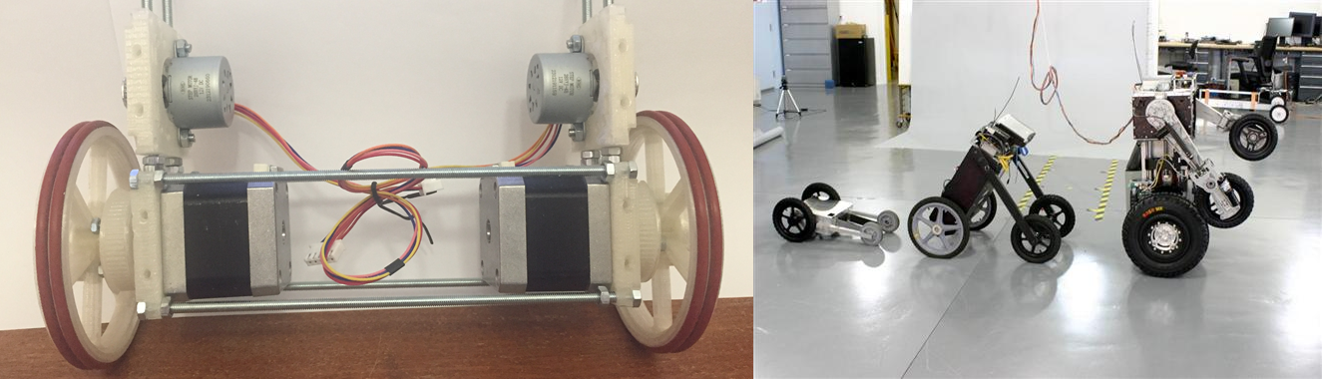
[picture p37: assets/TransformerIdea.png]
Transformance Idea


#### Use alternative painting technology

Using an alternative to pen painting technology will give you the freedom to use multiple colors (cyan, magenta, yellow, black and white) and to paint on both black and white surfaces. The use of the CMYK color model will make it possible to paint even true color pictures. Different methods to atomize liquid paint, like air (airbrushes), ultrasonic, electrostatic, etc., can be assessed and/or tested to find the best painting solution for the Adroid robots.

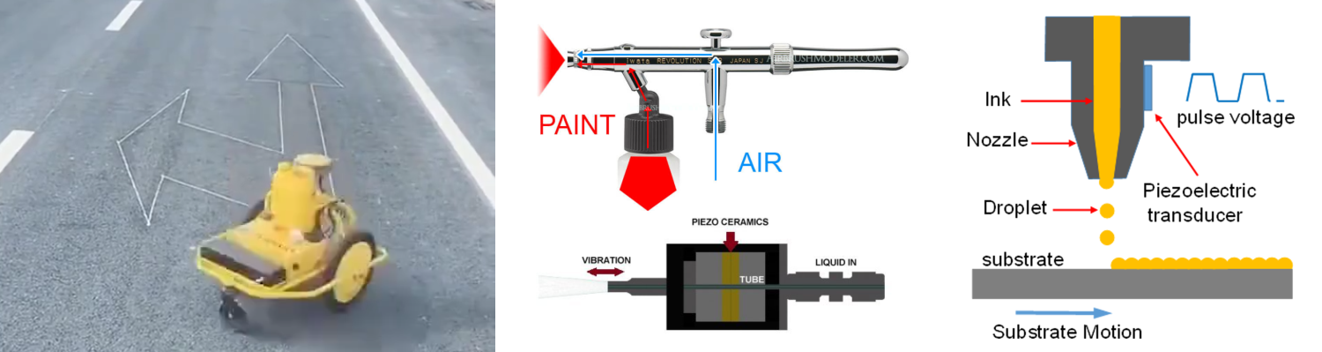
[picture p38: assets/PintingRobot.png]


#### Some alternatives it can be assessed and/or tested

Alternatives to be assessed and tested:

* Captain (rope) gear for body movement using two arms schematics
* Strain gauge sensor made as PCB including all electronic staff
* Absolute positioning rotational sensor (360 degree) for head and arms

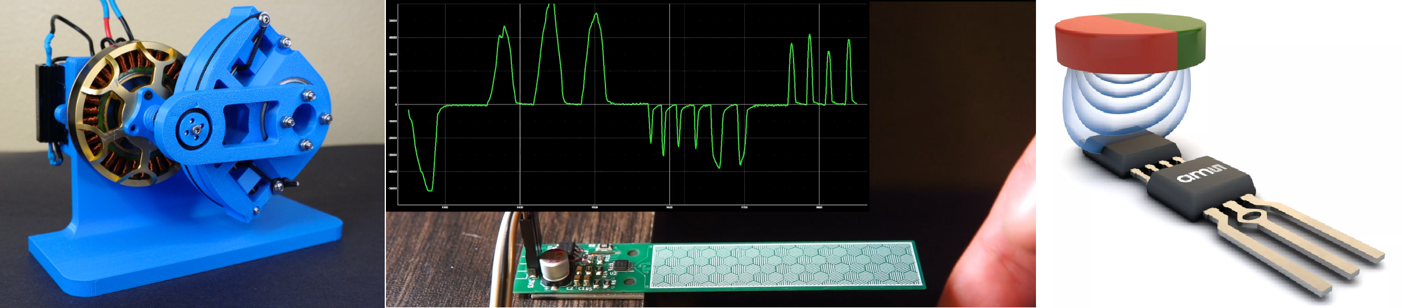
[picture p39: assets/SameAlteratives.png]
Same Alteratives


## First real prototypes

#### Mechanical design prototypes

Three real Adroid prototypes (the Small, the Tall and the Wide) are shown in the picture below. It was chosen to use NEMA 42HB34 stepper motors for the main robot movement and 28BYJ-48 geared stepper motors as auxiliary with ULN2003 drivers for body and head movement. The body movement is based on a single stepper motor, belt gear based on 16- and 60-tooth GT2 pulleys, and an arm with a pair of ball bearing free wheels on springs. Two of them (the Tall and the Wide) are running on their RPi 5 boards Linux OS and a dual camera streaming server with ePTZ control written on Python. The RPi 5 boards are powered by 3S Li-Po UPS modules. The head movement (pan only) of these two prototypes is based on a single auxiliary geared stepper motor. The Small Adroid prototype (low budget variant) contains three RPi Pico MCUs and ULN2003 drivers for stepper motor control, two MCUs with a 2 MP OV2640 SPI camera and microphone each, and one for the server staff based on the Seeed Studio XIAO ESP32S3 Sense modules. All these low consumption modules are extremely small (21mm x 17,5mm) and have 8MB RAM, 8MB of flash, 2.4GHz Wi-Fi, BLE 5.0, a wide set of interfaces, and can be programmed via their USB-C connector.

Prototypes

#### Some software staff developed and/or tested (short videos)

##### Head and body movement using geared stepper motors controled by RPi Pico PIO

Van Hunter Adams' algorithm for the RPi Pico PIO is downloaded, built and tested on the head and body movement auxiliary geared stepper motors in the Small Adroid prototype. For the building of the firmware, Linux OS on the RPi 5 board at the Wide Adroid prototype is used. The complete set of the RPi Pico C/C++ SDK and all the required libraries and tools to build and flash it on the target are also installed. The video shows synchronized body and head movements controlled by the RPi Pico PIO. The animation with 46.5 fps visible on the 3.2" TFT SPI display is generated on a separate overclocked at 250 MHz RPi Pico MCU using the TFT_eSPI library and transferred over SPI at 62.5 MHz.

<video controls playsinline autoplay loop muted width="100%"
    src="https://github.com/user-attachments/assets/fc1d304b-d6ce-423e-b7e3-0300df6fe03b" type="video/webm">
</video>

##### Dual camera streaming server with ePTZ control

The next video is a compilation of a user interface based Web Sockets and remote terminals running corresponding server staff and shows the real time ePTZ control of both cameras. In addition, the almost real time video streaming and its low latency are observable thanks to embedded and synchronized clocks running at both server and user ends.

<video controls playsinline autoplay loop muted width="100%"
    src="https://github.com/chradev/pi-h264-to-browser-streamer/assets/11261306/cbac77e0-3cdb-4b67-8a05-6e53c996912c" type="video/mp4">
</video>

#### 3D printed unified details and wide mount variant with own wheel design

In the picture below is shown the second generation of 3D printed unified details, including own Pololu like driving wheel with two O-rings, hub and 60-tooth GT2 pulley. It is planned instead of a single motor with belt gear and a single arm with a pair of free ball bearing wheels for body movement to use a dual arm scheme with a directly coupled geared stepper motor, a nylon pulley with bearing, a PCB made strain gauge, and a pair of hall sensors for each arm. On the photo is shown a new prototype variant with two body movement auxiliary geared stepper motors.

3D Printing Details

#### Third party components

The components shown on the picture are before the second generation of 3D printed unified details and include Pololu wheels and belt geared body movement scheme staff.

Third Party Staff

#### Simulated design configurations

The simulation web application was developed in the very beginning and did not reflect later modifications made in prototyping process.

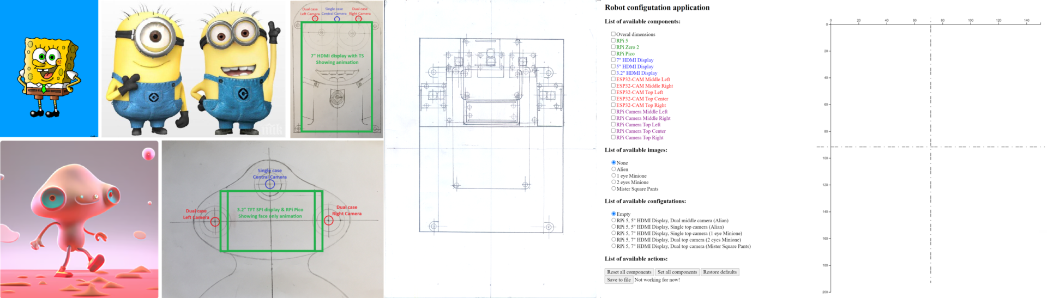
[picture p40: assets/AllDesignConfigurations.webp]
All Design Configurations


### Related projects and links

Some of the links include staff from different projects, investigations and tests that could be used in the current development process.

 * <a href="https://github.com/chradev/Adroid" target="_blank">Adroid on Github</a>
 * <a href="https://en.wikipedia.org/wiki/User:Chradev/Adriod" target="_blank">Adroid on Wikipedia</a>
 * <a href="https://github.com/chradev/steam-robot-design-simulator" target="_blank">A simple web application to test different design configurations of S.T.E.A.M. robots</a> 
 * <a href="https://github.com/chradev/pi-h264-to-browser-streamer" target="_blank">Dual camera, near-real-time, h.264 video streamer from RPi 5 to a bowser</a> 
 * <a href="https://github.com/chradev/Adroid/blob/main/assets/pdfs/DesignNotes.pdf" target="_blank">Own implementation of open source intelligent robot - startup design notes (PDF)</a> 
 * <a href="https://github.com/chradev/Unified-ILI9341-Graphic-Test" target="_blank">Unified ILI9341 Graphic Test</a> 
 * <a href="https://github.com/chradev/Unified_ili9340_Graphic_Test_plus" target="_blank">Unified ili9340 Graphic Test plus</a> 
 * <a href="https://github.com/chradev/DrawWithDMA" target="_blank">DrawWithDMA</a> 
 * <a href="https://github.com/chradev/Adroid/blob/main/assets/pdfs/Unified_Multicore_Low_Power_IoT_Platform.pdf" target="_blank">Unified Multicore Low Power IoT Platform (PDF)</a> 
 * Open S.T.E.A.M. initiative (PDFs): <a href="https://github.com/chradev/Adroid/blob/main/assets/pdfs/OpenSTEAM.pdf" target="_blank">En</a>, <a href="https://github.com/chradev/Adroid/blob/main/assets/pdfs/OpenSTEAM_bg.pdf" target="_blank">Bg</a>  

Updated by ChRadev on 15.1.2026

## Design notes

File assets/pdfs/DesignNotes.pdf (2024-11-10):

## Own implementation of open source intelligent robot – startup design notes

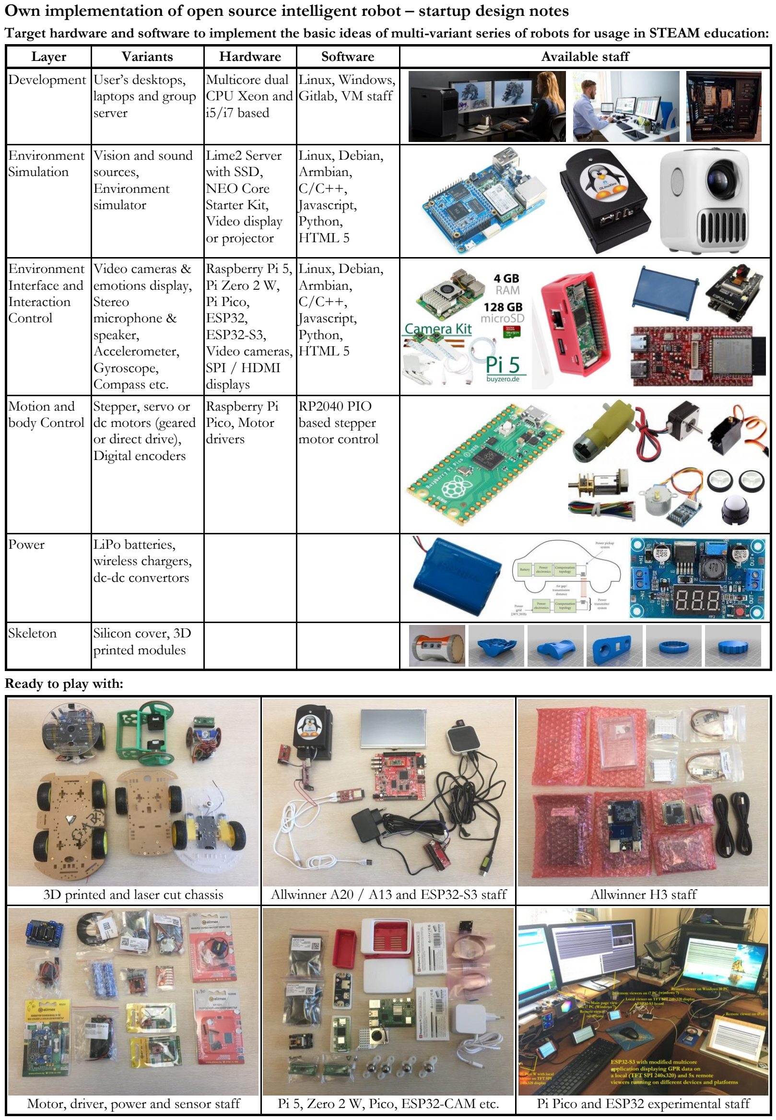
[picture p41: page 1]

Target hardware and software to implement the basic ideas of multi-variant series of robots for usage in STEAM education:

Layer | Variants | Hardware | Software | Available staff
Development | User’s desktops, laptops and group server | Multicore dual CPU Xeon and i5/i7 based | Linux, Windows, Gitlab, VM staff
Environment Simulation | Vision and sound sources, Environment simulator | Lime2 Server with SSD, NEO Core Starter Kit, Video display or projector | Linux, Debian, Armbian, C/C++, Javascript, Python, HTML 5
Environment Interface and Interaction Control | Video cameras & emotions display, Stereo microphone & speaker, Accelerometer, Gyroscope, Compass etc. | Raspberry Pi 5, Pi Zero 2 W, Pi Pico, ESP32, ESP32-S3, Video cameras, SPI / HDMI displays | Linux, Debian, Armbian, C/C++, Javascript, Python, HTML 5
Motion and body Control | Stepper, servo or dc motors (geared or direct drive), Digital encoders | Raspberry Pi Pico, Motor drivers | RP2040 PIO based stepper motor control
Power | LiPo batteries, wireless chargers, dc-dc convertors
Skeleton | Silicon cover, 3D printed modules

### Ready to play with:

3D printed and laser cut chassis | Allwinner A20 / A13 and ESP32-S3 staff | Allwinner H3 staff
Motor, driver, power and sensor staff | Pi 5, Zero 2 W, Pico, ESP32-CAM etc. | Pi Pico and ESP32 experimental staff

## Emotional and human like functionality of the robot

## Human like activities

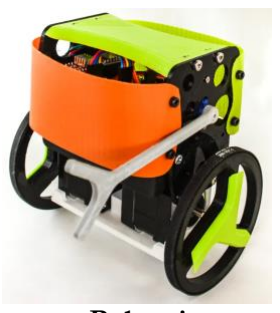
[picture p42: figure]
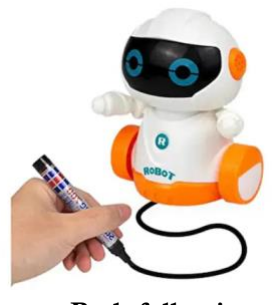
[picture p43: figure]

Balancing | Communicating | Dancing | Drawing | Path following | Show emotions

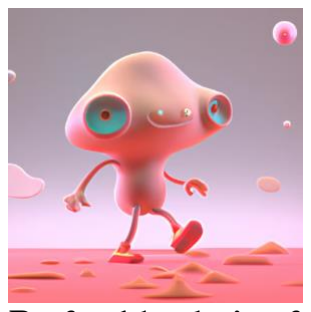
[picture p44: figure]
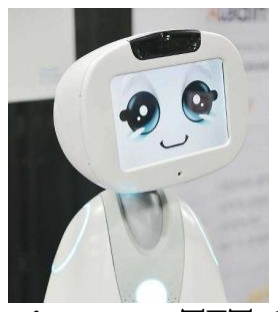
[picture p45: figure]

## Preferable choice for head look and possible face simulations on a TFT display

## Face variants with stereo audio & vision:

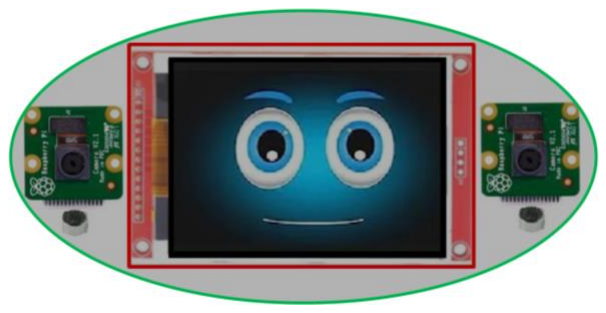
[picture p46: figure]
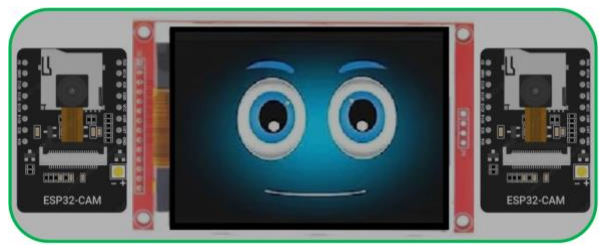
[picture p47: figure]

Combination of 3.2” TFT SPI display, dual ESP32-CAM | Combination of 3.2” TFT SPI display, dual Raspberry Pi
modules, Raspberry Pi Zero 2 W and Pi Pico | Camera Module 2, Raspberry Pi 5 and Pi Pico
- Face size: 140 x 55 mm (rounded rectangle in green); | • Face size: 140 x 70 mm (ellipse in green);
- 3.2” TFT SPI display size: 90 x 54 mm (picture); | • 3.2” TFT SPI display size: 90 x 54 mm (central picture);
- 2MP ESP32-CAM module size: 24 x 40 mm (pictures); | • 8MP Raspberry Pi Camera ver. 2 size: 24 x 25 mm (picture);
- Raspberry Pi Pico size: 51 x 21 mm (not visible); | • Raspberry Pi Pico size: 51 x 21 mm (not visible);
- Raspberry Pi Zero 2 W size: 65 x 30mm (not visible). | • Raspberry Pi 5 size: 85 x 56mm (rectangle in red).

### Notes:

- Raspberry Pi Pico will control TFT SPI display and will generate emotional animation;
- Second Raspberry Pi Pico will control motors and robot motion and positioning;
- Raspberry Pi 5 or Pi Zero 2 W will control head/eyes motion, audio and video streams and environment interactions;
- Lime2 Server or NEO Core Starter Kit (both with SSD) will be used as a base station and environment simulator.

## Some useful links to open source emotional robots:

Awesome-social-robots: (https://github.com/jcarolinares/awesome-social-robots) A list of resources, ideas, and projects to create Open Source Social Robots;
Direct Digital Synthesis (https://vanhunteradams.com/DDS/DDS.html) thanks to V. Hunter Adams (vha3@cornell.edu);
VoiceGPT (https://github.com/nickbild/voice_chatgpt) is a voice assistant that leverages the powerful ChatGPT chatbot to answer your questions;
Snowboy Hotword Detection: (https://github.com/seasalt-ai/snowboy) DNN based hot word and wake word detection toolkit (model generation included).

### EWON Raspberry Pi Powered Home Robot

on Instructables (https://www.instructables.com/EWON-Raspberry-Pi-Powered-Home-Robot/) and Thingiverse; (https://www.thingiverse.com/thing:4511545/files)

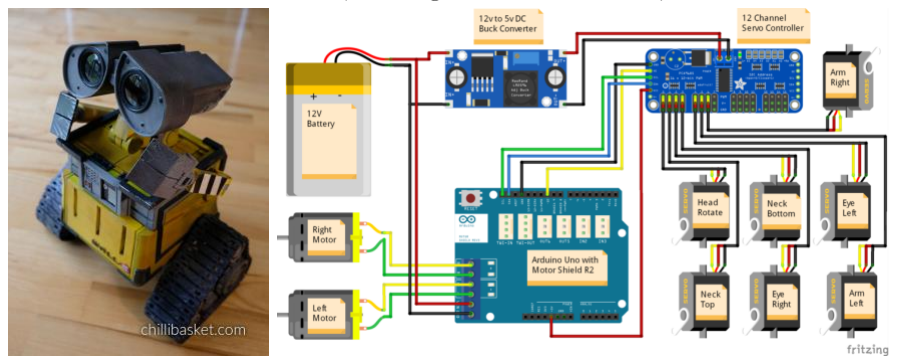
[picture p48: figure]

### 3D Printed WALL·E (https://wired.chillibasket.com/3d-printed-wall-e/)

## Performance measurement of the available Linux boxes

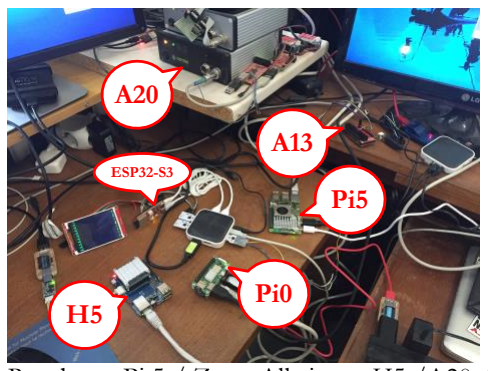
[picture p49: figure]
ESP32-S3
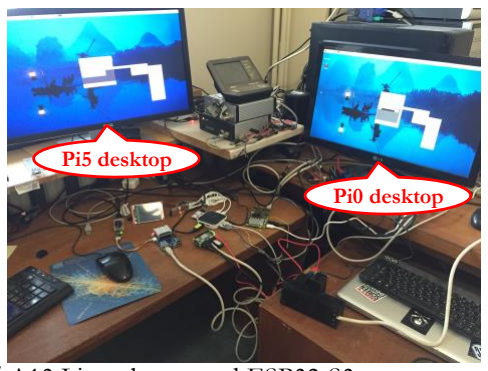
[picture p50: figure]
Pi0 desktop; Pi5 desktop

### Raspberry Pi 5 / Zero, Allwinner H5 /A20 / A13 Linux boxes and ESP32-S3 setup

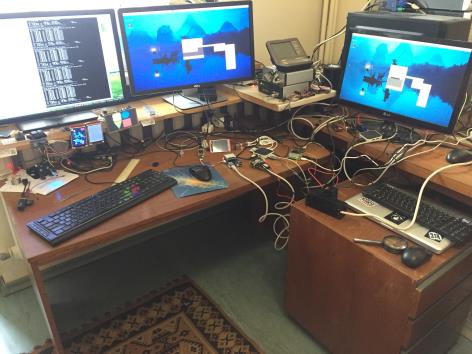
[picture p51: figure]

Raspberry Pi 5 Model B, 4GB (8GB is also available) | 163x
Hardware | Broadcom BCM2712 quad-core 64-bit Arm Cortex A76 CPU up to 2.4GHz; VideoCore VII GPU with Dual 4Kp60 HDMI display output; 4GB SDRAM; 32GB SD card; Dual-band 802.11ac Wi-Fi; Bluetooth 5.0 / BLE; 1Gb Ethernet; Dell P2415Q display on HDMI0 @ 1600x1200 (4k is supported); Active Cooler; 27W Power supply
Image maker / file | Raspberry Pi Imager / 2023-12-05-raspios-bookworm-arm64-full.img.xz
uname –a (after upgrade) | Linux rp5 6.1.0-rpi8-rpi-2712 #1 SMP PREEMPT Debian 1:6.1.73-1+rpt1 (2024-01-25) aarch64 GNU/Linux
lscpu | Architecture: aarch64; CPU op-mode(s): 32-bit, 64-bit; Byte Order: Little Endian; CPU(s): 4; Vendor ID: ARM; Model name: Cortex-A76; Thread(s) per core: 1; Core(s) per cluster: 4; CPU max: 2.4GHz; CPU min: 1.5GHz; BogoMIPS: 108.0
sysbench cpu --threads=4 run | CPU speed: events per second: 10,920.28; Latency (ms): min: 0.36; avg: 0.37; max: 1.06; 95th percentile: 0.37
iperf3 -c 192.168.1.178 | 10.00 sec 924 MBytes 775 Mbits/sec 10 sender; 10.00 sec 923 MBytes 774 Mbits/sec receiver
Geekbench 6 | Raspberry Pi 5 Model B Rev 1.0 ARM ARMv8 2.4GHz (1 cores, 4 threads) | Linux | AArch64 | 799 | 1635
Raspberry Pi Zero 2 W (passive cooling will be a problem in a box) | 29x
Hardware | Custom SIP RP3A0 quad-core 64-bit ARM Cortex-A53 CPU up to 1GHz; GPU with Dual 4Kp60 HDMI® display output; 512MB SDRAM; 32GB SD card; 2.4GHz 802.11 b/g/n Wi-Fi; Bluetooth 4.2 / BLE; USB hub with 100Mb Ethernet; LG W2261VP display on HDMI @ 1920x1080 (HD is supported); Passive Cooler; 10W Power supply
Image maker / file | Raspberry Pi Imager / 2023-12-05-raspios-bookworm-arm64-full.img.xz
uname –a (after upgrade) | Linux rp0 6.1.0-rpi8-rpi-v8 #1 SMP PREEMPT Debian 1:6.1.73-1+rpt1 (2024-01-25) aarch64 GNU/Linux
lscpu | Architecture: aarch64; CPU op-mode(s): 32-bit, 64-bit; Byte Order: Little Endian; CPU(s): 4; Vendor ID: ARM; Model name: Cortex-A53; Thread(s) per core: 1; Core(s) per cluster: 4; CPU max: 1GHz; CPU min: 600MHz; BogoMIPS: 38.4
sysbench cpu --threads=4 run | CPU speed: events per second: 1,956.53; Latency (ms): min: 2.03; avg: 2.04; max: 3.18; 95th percentile: 2.03
iperf3 -c 192.168.1.178 | 10.00 sec 113 MBytes 94.6 Mbits/sec 10 sender; 10.00 sec 112 MBytes 94.2 Mbits/sec receiver
NanoPi NEO Core-LTS (Starter Kit) | 3x
Hardware | Allwinner H3 quad-core ARM Cortex-A7 CPU up to 1.2GHz; 512MB SDRAM; 4GB SD card; USB hub with 100Mb Ethernet; Passive Cooler; USB powered
Image maker / file | USBImager v.1.0.10 / Armbian_23.11.1_Nanopineo_bookworm_current_6.1.63.img.xz
uname –a (after upgrade) | Linux nanopineo 6.1.63-current-sunxi #1 SMP Mon Nov 20 10:52:19 UTC 2023 armv7l GNU/Linu
lscpu | Architecture: arm7l; Byte Order: Little Endian; CPU(s): 4; Vendor ID: ARM; Model name: Cortex-A7; Thread(s) per core: 1; Core(s) per socket: 4; CPU max: 1.296GHz; CPU min: 480MHz; BogoMIPS: 48.0
sysbench cpu --threads=4 run | CPU speed: events per second: 198.02; Latency (ms): min: 20.01; avg: 20.16; max: 54.44; 95th percentile: 20.00
iperf3 -c 192.168.1.178 | 10.00 sec 113 MBytes 94.6 Mbits/sec 10 sender; 10.00 sec 112 MBytes 94.2 Mbits/sec receiver
A20-OLinuXino-LIME-8GB eMMC (Own box – old setup) | 1x
Hardware | Allwinner A20 dual-core ARM Cortex-A7 CPU up to 1GHz; Mali 400 GPU with HDMI output (HD is supported); 1GB DDR3 RAM; 8GB eMMC; 480GB SATA SSD; 1Gb Ethernet; Passive Cooler; 15W Power supply
Image maker / file | Win32DiskImager v.1.0 / Armbian_5.27_Lime2-emmc_Debian_jessie_next_4.10.5.img
uname -a (own build) | Linux egpr 4.10.5-sunxi #4 SMP Wed Mar 22 23:38:40 EET 2017 armv7l GNU/Linu
lscpu | Architecture: arm7l; Byte Order: Little Endian; CPU(s): 2; Thread(s) per core: 1; Core(s) per socket: 2; Model name: ARMv7 Processor rev 4 (v7l); CPU max: 960MHz; CPU min: 144MHz; BogoMIPS: 27.78
sysbench cpu --threads=2 run | CPU speed: events per second: 66.93; Latency (ms): min: 29.23; avg: 29.87; max: 59.99; 95th percentile: 31.20
iperf3 -c 192.168.1.178 | 10.00 sec 112 MBytes 94.3 Mbits/sec 10 sender; 10.00 sec 112 MBytes 94.0 Mbits/sec receiver
A13-SOM-512 & A13-SOM-WIFI-4GB (modified) | 0.55x
Hardware | Allwinner A13 ARM Cortex-A8 CPU up to 1GHz; 512MB DDR3 RAM; 4GB NAND Flash; USB hub; 32GB USB flash disk; USB WiFi; 100Mb Ethernet; No Cooler; USB powered
Image maker / file | Win32DiskImager v.1.0 / A13-OLinuXino-jessie-base-20230217-181328.img.7z
cat /proc/version | Linux version 5.10.105-olimex Debian 8.3.0-2 #181328 SMP Fri Feb 17 18:14:43 UTC 2023
lscpu | Architecture: arm7l; Byte Order: Little Endian; CPU(s): 1; Thread(s) per core: 1; Core(s) per socket: 1; Vendor ID: ARM; Model name: Cortex-A8; CPU max: 1GHz; CPU min: 432MHz
sysbench cpu --threads=2 run | CPU speed: events per second: 36.72; Latency (ms): min: 26.82; avg: 27.19; max: 45.54; 95th percentile: 28.16
iperf3 -c 192.168.1.178 | 10.00 sec 112 MBytes 94.2 Mbits/sec 10 sender; 10.00 sec 112 MBytes 93.8 Mbits/sec receiver
Notes: | iPerf3 server is running on 4-core i7 Windows 7 PC, 1Gb Ethernet infrastructure; ESP32-S3 is not running Linux and no performance tests were done.

## Compact and Robust 3D Printed Animatronic Eye Mechanism

## Main start up points:

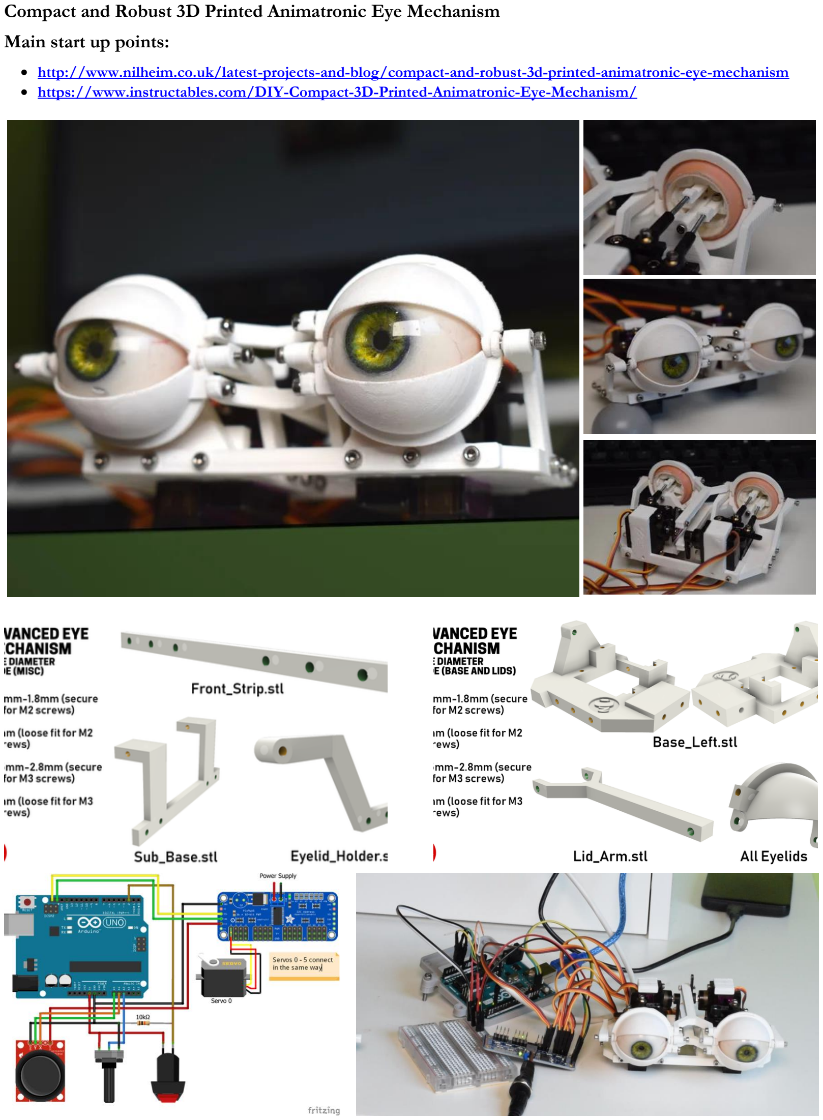
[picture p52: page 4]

- http://www.nilheim.co.uk/latest-projects-and-blog/compact-and-robust-3d-printed-animatronic-eye-mechanism

### - https://www.instructables.com/DIY-Compact-3D-Printed-Animatronic-Eye-Mechanism/

## ZeroBot Pro – Raspberry FPV Robot

Main start up point – ZeroBot Pro – Raspberry FPV Robot (https://www.thingiverse.com/thing:2800717)

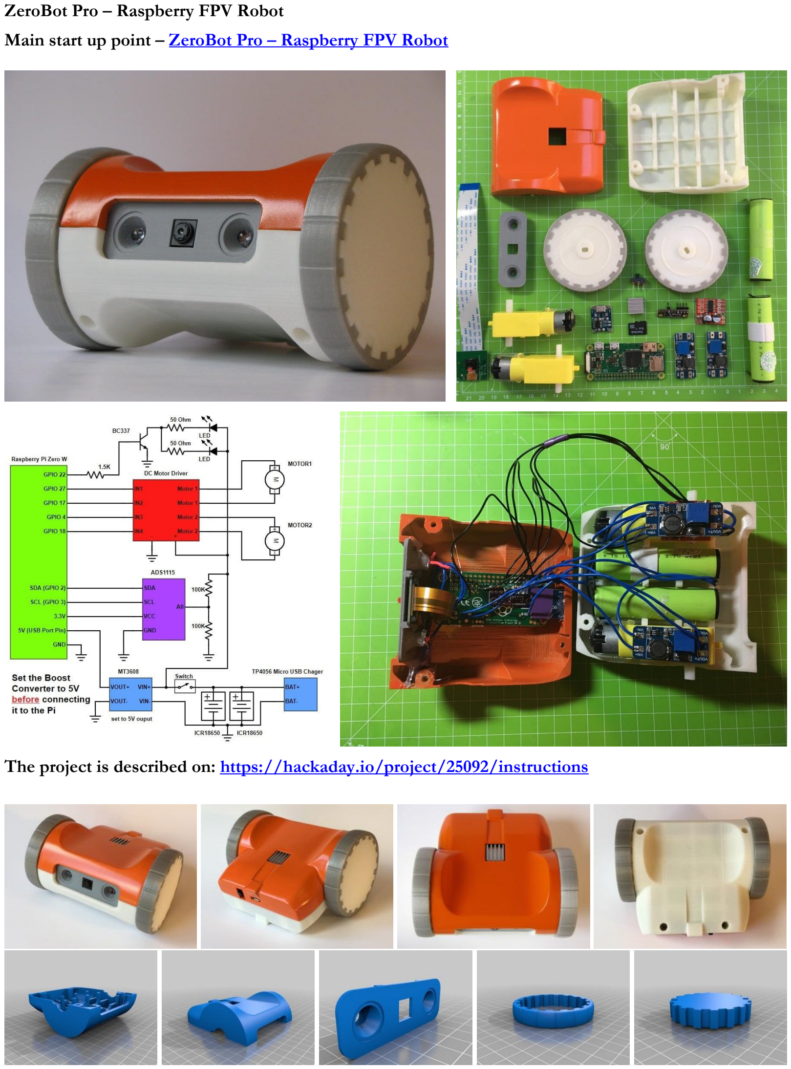
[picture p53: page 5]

## The project is described on: https://hackaday.io/project/25092/instructions

## Open Source Intelligent Robot (OSIR)

Main start up point – Open Source Turtle Robot (OSTR) (https://github.com/aspro648/OSTR/tree/master)

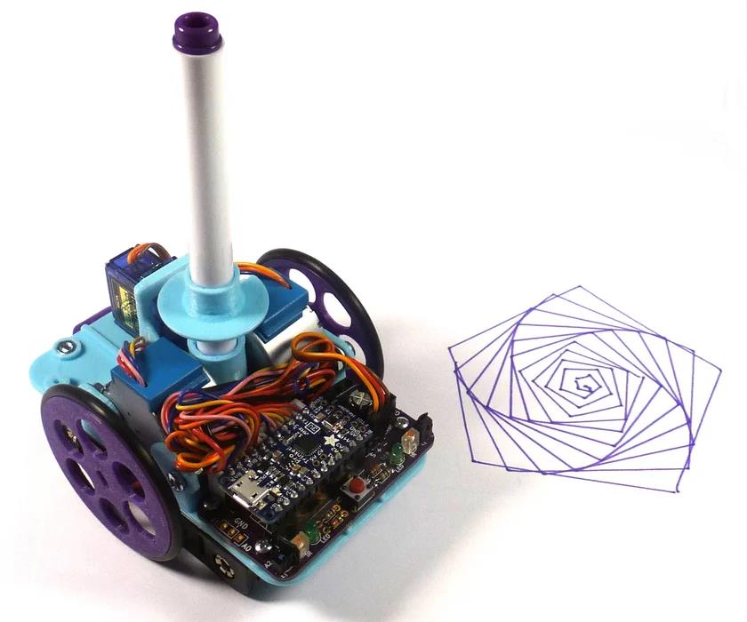
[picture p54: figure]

## The project is described on: https://www.instructables.com/OSTR/

## Electronics:

Turtle Robot Board Kit | Will be changed, TFT SPI 3.2”Display
Adafruit ItsyBitsy Microcontroller (M4 recommended) | AVR32D48 and ESP32 module or Linux box
USB micro cable | For programming only

## Electromechanical:

## 2 Geared 5V 28byj Steppers 1 Micro servo

2 2 x AA Battery Holders | No holder
4 AA batteries | BATTERY-LIPO4400mAh

## 3D Parts:

## Chassis 2 wheels Caster

## Hardware:

## M3 screws and nuts 5/8 steel bearing 2 Dash 223 O-rings

## Software:

Main staff | Web server and client, Web Sockets, JS control application, CircuitPython runtime
Languages | C/C++, Python, HTML 5, JavaScript
Libraries | Turtle, Adafruit CircuitPython Bundle

## Main electromechanical and 3D parts from OSTR:

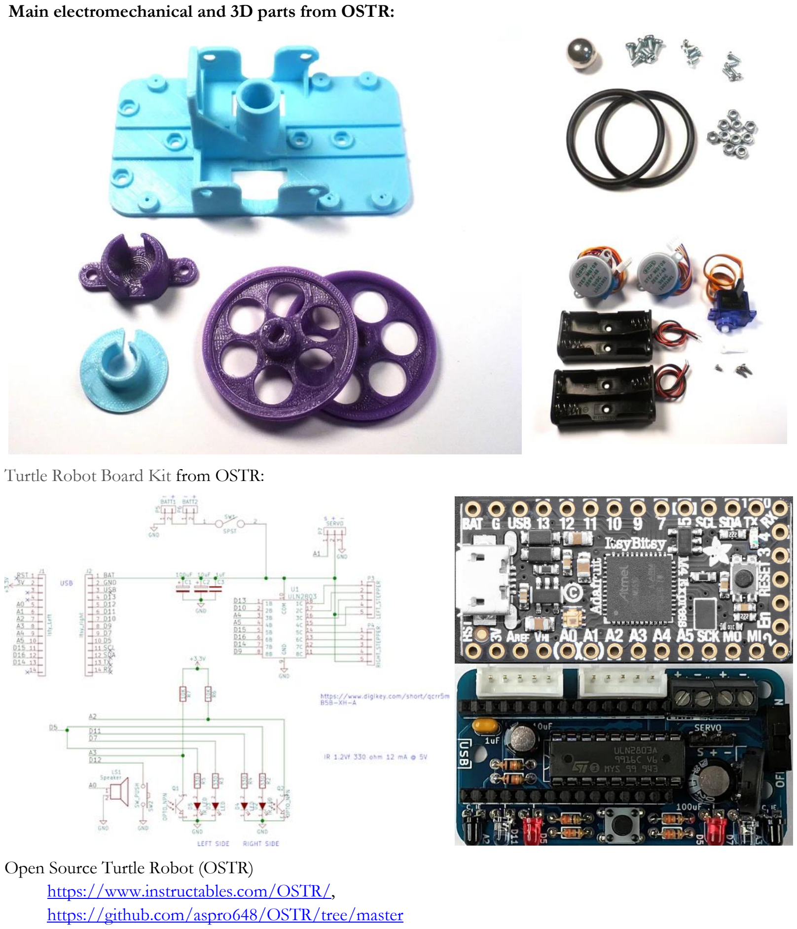
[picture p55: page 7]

## Turtle Robot Board Kit from OSTR:

## Open Source Turtle Robot (OSTR)

https://www.instructables.com/OSTR/,

## https://github.com/aspro648/OSTR/tree/master

## DIY ESP32 Wifi Self Balancing Robot and Android Application

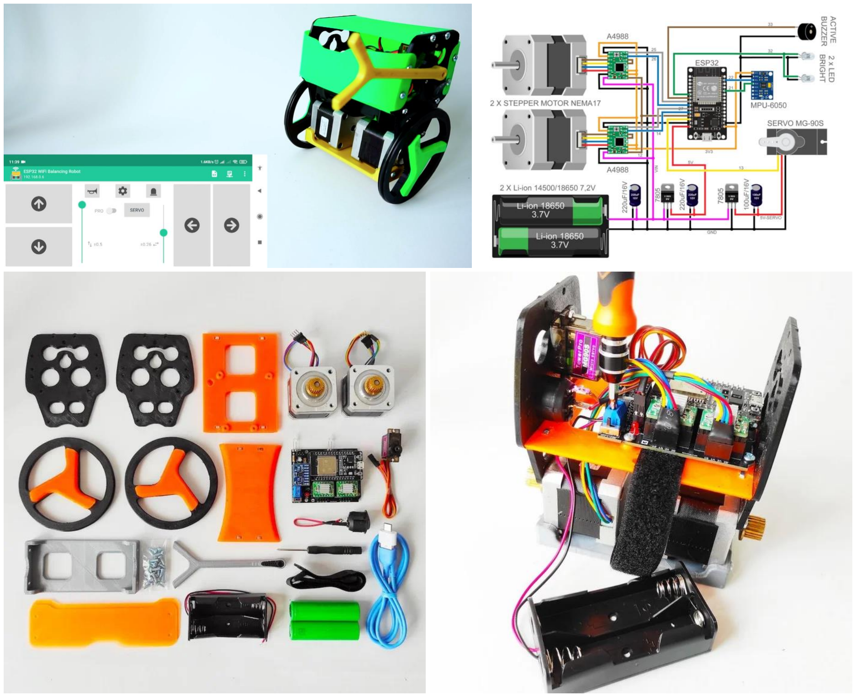
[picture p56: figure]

## DIY ESP32 Wifi Self Balancing Robot and Android Application

- https://www.instructables.com/DIY-ESP32-Wifi-Self-Balancing-Robot-B-Robot-ESP32-/,
- https://github.com/bluino/esp32_wifi_balancing_robot,

## - https://play.google.com/store/apps/details?id=com.bluino.esp32wifibalancingrobot&pli=1

## Wifi Camera Robot Car based on ESP32 CAM

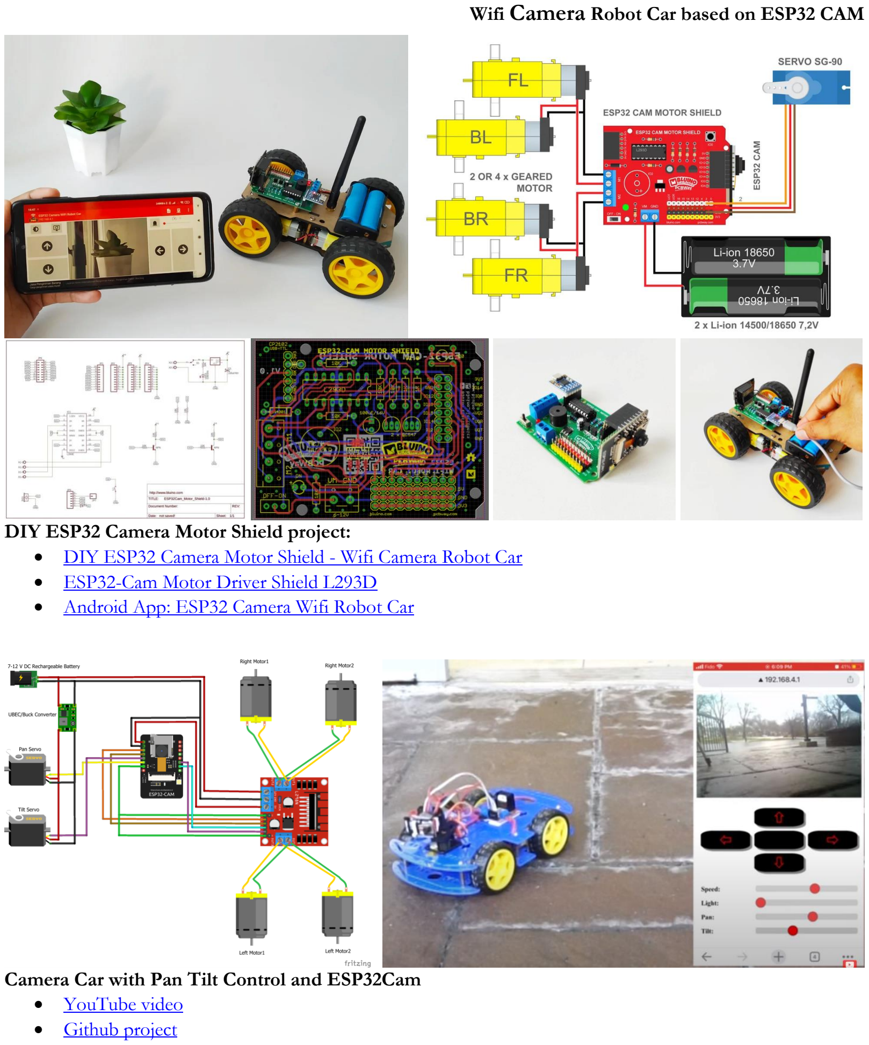
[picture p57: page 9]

## DIY ESP32 Camera Motor Shield project:

- DIY ESP32 Camera Motor Shield - Wifi Camera Robot Car (https://www.instructables.com/DIY-ESP32-Camera-Motor-Shield-Wifi-Camera-Robot-Ca/)
- ESP32-Cam Motor Driver Shield L293D (https://www.pcbway.com/project/shareproject/ESP32_Cam_Motor_Driver_Shield_L293D.html)
- Android App: ESP32 Camera Wifi Robot Car (https://play.google.com/store/apps/details?id=com.bluino.esp32camerawifirobotcar)

## Camera Car with Pan Tilt Control and ESP32Cam - YouTube video (https://www.youtube.com/watch?v=tyY7AN132Xs)

- Github project (https://github.com/un0038998/CameraCarWithPanTiltControl/blob/main/Diagrams/Camera%20Car%20With%20PanTilt%20Control.png)

## Low-Budget XY Plotter Drawing Robot Board

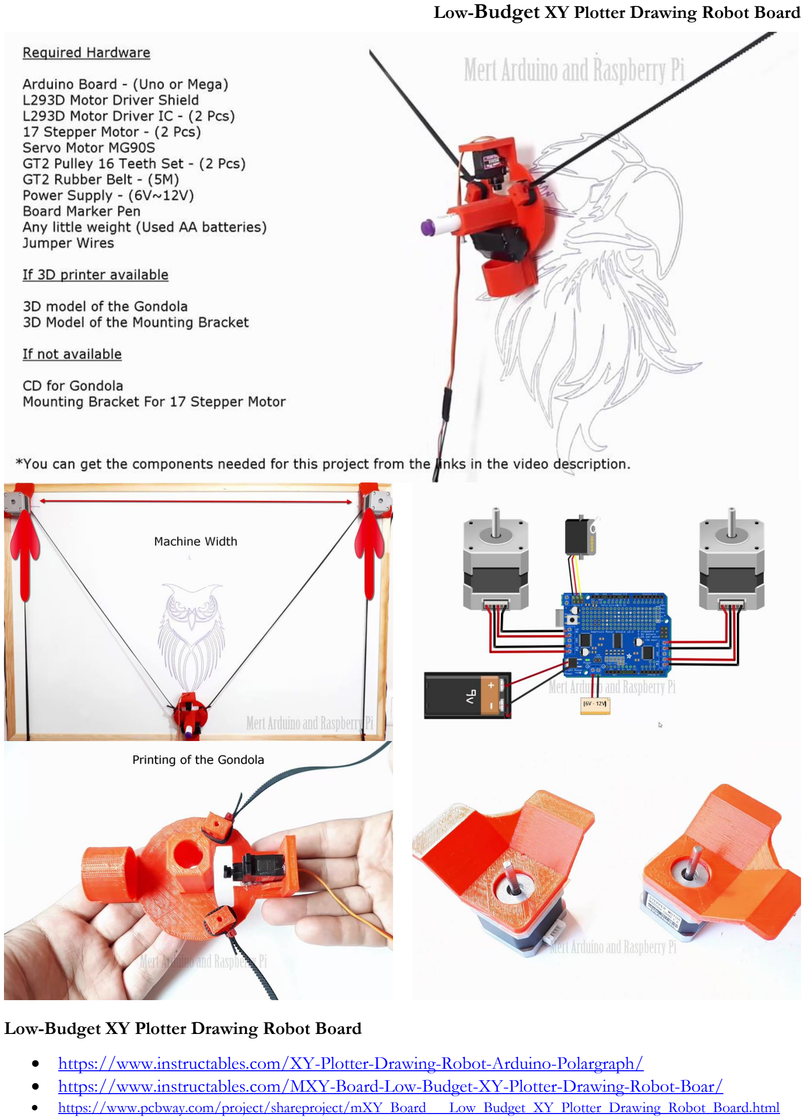
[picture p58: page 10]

## Low-Budget XY Plotter Drawing Robot Board

## - https://www.instructables.com/XY-Plotter-Drawing-Robot-Arduino-Polargraph/ - https://www.instructables.com/MXY-Board-Low-Budget-XY-Plotter-Drawing-Robot-Boar/

- https://www.pcbway.com/project/shareproject/mXY_Board___Low_Budget_XY_Plotter_Drawing_Robot_Board.html

## Some ideas for internal design thanks to Van Hunter Adams (vha3@cornell.edu)

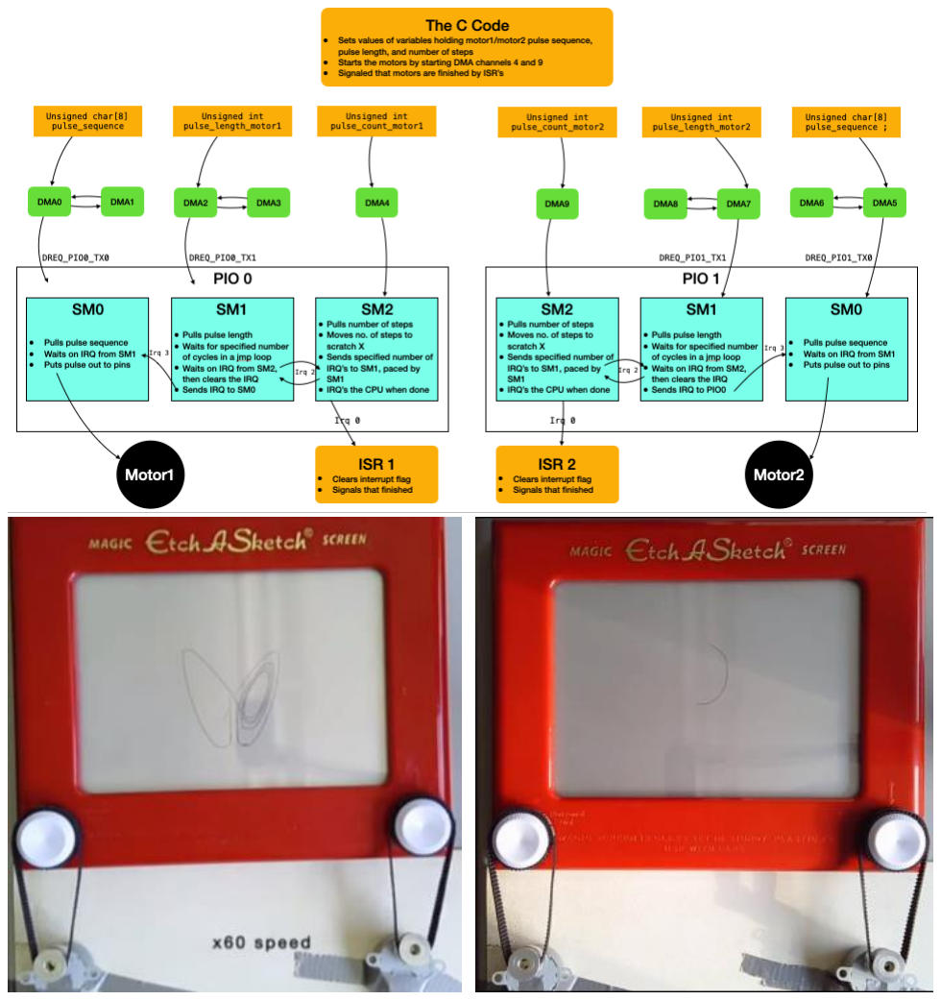
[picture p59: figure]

PIO-Based Stepper Motor Driver for RP2040 https://github.com/vha3/Hunter-Adams-RP2040-Demos/tree/master/Stepper_Motors (https://github.com/vha3/Hunter-Adams-RP2040-Demos/tree/master/Stepper_Motors) https://vanhunteradams.com/Pico/Steppers/Lorenz.htmlhttps://vanhunteradams.com/DDS/DDS.html

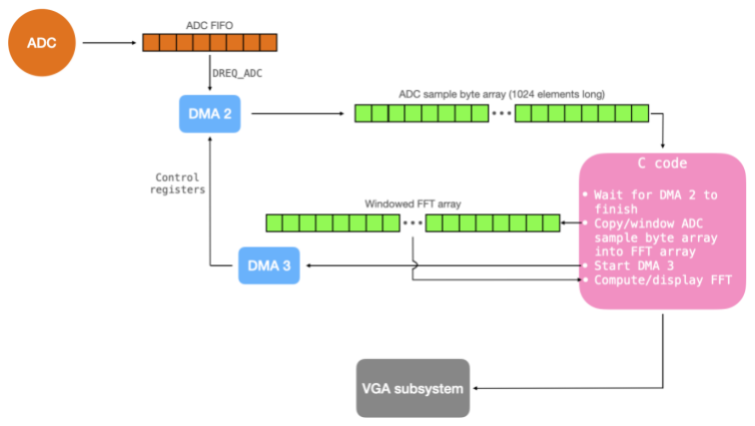
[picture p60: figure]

Real-time Audio FFT to VGA Display with RP2040 (Raspberry Pi Pico) https://vanhunteradams.com/Pico/VGA/FFT.html

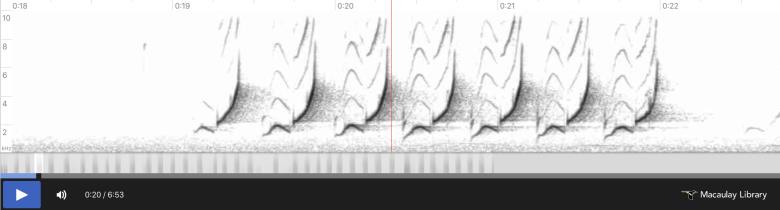
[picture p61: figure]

Direct Digital Synthesis
https://vanhunteradams.com/DDS/DDS.htmlhttps://vanhunteradams.com/Pico/Cricket/Crickets.htmlhttps://github.com/vha3/Hunter-Adams-RP2040-Demos/tree/master/Audio

Pulse-Width Modulation Demonstrations https://github.com/vha3/Hunter-Adams-RP2040-Demos/tree/master/PWMhttps://vanhunteradams.com/Pico/ReactionWheel/HBridgeCircuit.html

# Some ideas for external design

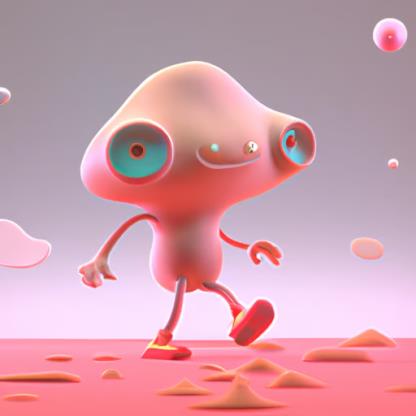
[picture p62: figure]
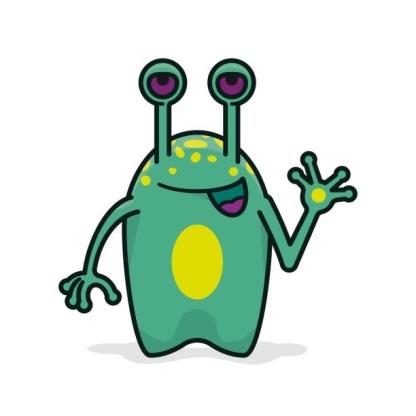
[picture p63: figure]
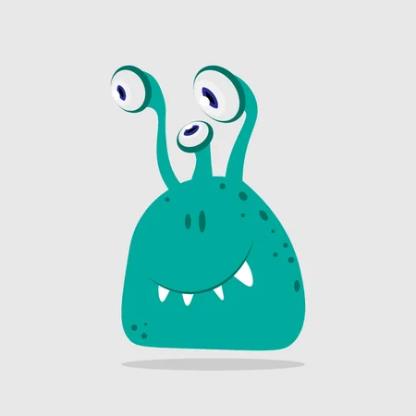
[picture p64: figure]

Portrait / landscape body with TFT display, 2 wheels mechanics, 1-3 eye like movable cameras, 4-pen drawing set etc.

# Some ideas for the web interface and main staff

- Will be able to balance, dance, draw, show emotions, follow visual paths and audio commands and other human activities;
- Will use http(s) protocol over direct (WiFi AP) or indirect (WiFi STA via local router) connection with control application running into the user’s web browser (modern versions);

### - Robot can be programmed by the following methods:

- Using the open source firmware code;
- Visual programming by blocks with translation to Python and/or JavaScript script and running in the simulator;
- Programming with built-in JavaScript interpreter and/or Python runtime and running in the simulator;
- Loading of vector images with translation to JavaScript and/or Python script and running in the simulator;

### - The robot will have:

- 2 microphones, 2 loudspeakers and stereo amplifier with possibility to talk via connection;
- a camera for watching the video in user’s control application;
- the microphones and camera can be used for robot control;
- home station with wireless battery charger and “go-to-home” mode;

### - In advanced version the robot will have:

- built-in Linux box with WiFi and directly connected to internal MCU;
- stereo camera connected to the Linux box for stereo vision;
- All versions will have TFT display for emotions showing controlling with separate MCU.

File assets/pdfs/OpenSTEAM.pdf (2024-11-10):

Open S.T.E.A.M. – the way for sustainable development of the society

It is my pleasure to announce the idea for creating of a (plat-)form for communication between enthusiasts (scientists, professionals, men of arts, students, scholars and even children) who have free resources such as knowledge, motivation, personal and/or machine time and space, hardware, software tools and the like and are willing to invest them for free in common projects based on ideas like S.T.E.A.M. and Open Source in their broad sense to create generally useful, high-tech and free products, including educational such in the field of electronics, computer science and robotics.

Both initiatives the Open Source and S.T.E.A.M. (Science – Technology – Engineering – Art – Math) are a pretty pair born by the informational society. On the one hand the movement started as "Open Source" by the computer professionals and spread in almost all aspects of the human life is the only real answer to the madness of the globalization. On the other hand S.T.E.A.M. idea comes from the need of the society to make the globalization trends a base for its sustainable development. Their union traces a reasonable way for the worth-life on the edge of next industrial revolution and the beginning of a new “Super Smart Society”.

The above thoughts are dictated by the realization of the fact that the industry's gluttony for a bigger and bigger profit by increasing the productivity while cutting the costs, especially for the skilled labor, is leading to an increase in the share of technology. Technological acceleration, in turn, accelerates the emergence and use of more and more new technologies. The dominance of such synchronous processes and the absence of counteraction lead to an exponential growth in the computer sciences, information technologies, artificial intelligence, automation, robotics etc. which can be seen in the graphs below.


Today’s exponential technological growth, rapid society development and industrial revolutions frequency lead to lowing of the life quality and stressed people

The above processes leads to a narrowing of the natural habitat of the smart and skilled people in our society which, in turn, decrease the quality of industrial products, services, human life and society at the end. One possible counteraction of the society is to increase the share of smart and skilled people, and the education is the only instrument for that.

The victory of open source over the closed products of the computer industry in recent decades has led to the expansion of this idea into many human domains and has proven to be a powerful means of countering many negative trends in globalization. That is why a logical and natural way for sustainable development of the society is S.T.E.A.M. education enriched with the ideas of Open Source in their broad sense. This is also the mission of the currently offered Open S.T.E.A.M. initiative.

### How the Open S.T.E.A.M. initiative will work?

Open S.T.E.A.M. is an initiative that will be practiced in real conditions and will be based on the following principles:
- Loyalty to foundation principles (S.T.E.A.M. and Open Source in their broad sense) and the good relationships between participants are a must;
- The initiative is open to every participant regardless of nationality, gender age and profession, and the English is common language of communication;
- Only related to the education, entertainment and required infrastructure activities are acceptable (no business, political, religious and other none related such);
- Every participant can be a donor, recipient or both and the infrastructure subject of donations or workmanship is free for usage by any participant;
- Any form of donation (personal time and space, material, nonmaterial, financial etc.) is acceptable and subject to public visibility incl. its usage;
- Activities of the participants performing organizational and/or management roles will be treated as donations and will not be paid;
- It is main duty of every participant to return back to the infrastructure the results of the activities achieved thanks to its free usage;
- Companies (incl. universities and schools) can also take part in the initiative as donors only but their staff will be treated as recipients;
- Recommended form of participation of the companies (especially the universities and the schools) is in the scientific, educational and entertaining processes;
- The only acceptable payment is for the participants spent their personal time and effort for education and/or entertainment of other participants on a regular basis (studies, classes, lessons, school works etc.). Promotion of paid activities is the only part that can be included in the initiative itself and the infrastructure will be available for free use as long as the participants are registered donors or recipients.

Donating blood means to donate a life; donating knowledge means to donate a better life!

Private persons Association Companies; Professionals Scientific workers Man of arts Students of any kind Scholars of any class Children or relatives; Donations Education Placement Installations Maintenance Management Subscriptions; Computer servers and workstations Mobile devices and LAN equipment Internet and service subscriptions Technical instruments and technologies Technical equipment and materials Software technologies and subscriptions Hardware and software projects Hardware instruments and workmanship Mechanical and art designs and ideas; Free usage Installation Maintenance Development Workmanship Cooperation; Professionals Scientific workers Man of arts Students of any kind Scholars of any class Children of any age

Donors | Activities | Infrastructure | Activities | Recipients

Mathematical models and program languages Scientific works, ideas and publications

All activities will be based on projects aimed at a real free-to-use product including its mathematical methods, program source code, electrical schematics, mechanical plans, manufacturing technology, etc. It is recommended that products produced with free resources be returned to infrastructure for free use by the members.

The Open S.T.E.A.M. initiative can be registered as non-profit organization in future and the structure can be changed to match the new realities without deviating from the principles described above.

### Some startup ideas and actions

The initial activities and participants necessary for the implementation of Open S.T.E.A.M. initiative are presented in the following figure:

Extracurricular learning | Scientific developments | Business projects | Web, Gitlab | Development boards | Modular robot
Laboratory exercises | Personal projects | Personal projects | Forum, Wiki | Prototype materials | MEM system
Graduation theses | Training | Training | Cloud, Meeting | Prototyping | RES monitor
Scientific developments | Donations | Donations | Linux VMs | 3D printing | Wind generator

Brief description of some of the active projects and prospects for implementation within Open S.T.E.A.M. the initiative:
- Intelligent modular robot (https://www.radevs.net/chradev/projects/DesignNotes.pdf) with fully open source programming, technical and mechanical components. The goal is the development of high-tech modules for movement, communication (wireless, audio and visual), control, programming, etc. The modules can be easily combined into robots with different qualifications (balancing, dancing, drawing, following voice commands and visual cues, showing emotions, etc.). The final prototypes will be programmable at all levels and can be used by users of any age for scientific research, education, even for fun. Since all components are fully open source, the work can be performed by anyone with the necessary skills and motivation, including for business or educational purposes. The project is in the initial phase and only part of the investigations has been done.
- Multi-channel Energy-Monitoring (MEM) system. (https://www.radevs.net/chradev/projects/Multichannel_Home_Electricity_Monitoring_System.pdf) The system is based on the OpenEnergyMonitor (https://github.com/openenergymonitor) project and is designed to measure both the total electricity consumption of a household and the consumption of individual appliances in order to minimize energy bills. The information is constantly collected and visualized through a local internet application including statistical analyses. To improve the accuracy of the measurement, a special test bench has been designed to allow the calibration of the sensors. In perspective, the application can integrate external and internal climate sensors as well as sensors for monitoring the supplied and/or produced electricity from local RES. A socially significant possibility is the creation of a public service (like air pollution control systems) to which all interested parties can anonymously send data about their personal consumption in order to control suppliers and/or the efficiency of local production of the electricity. The system can also be used for production sites. The project is in an advanced phase and some of the prototypes have been made and tested.
- System for monitoring the production of electrical energy from RES in combination with meteorological data. (https://www.radevs.net/chradev/projects/wind-gen/GreenEnergyMonitor.pdf) The system can also be used for RES parks, and some of its components can be integrated into the MEM system described above. The project is in an advanced phase and some of the prototypes have been made.
- Electric generator with medium power (5kW) for electricity production through wind turbines. (https://www.radevs.net/chradev/projects/wind-gen/WindGenHistoryEn.pdf) It can also be used as a module for installations with greater power. For the purposes of its investigation, a test bench has also been created and can be modified and used as an experimental and/or laboratory system for its study, both as a generator and as an electric motor, including in combination with batteries and accompanying controllers. Technically and technologically, the generator is suitable for production. The project is a completely original as development and is in an advanced phase, with detailed study of the prototypes.

Open S.T.E.A.M. initiative

Invitation letters

Teachers and students from universities and schools

Labs, Clubs
and Classes

Mentoring,
Membership

Professionals, scientific
workers, man of arts etc.

Donations Mentoring,
Membership

Persons, companies and
other organisations

Donations Mentoring,
Membership

Infrastructure buildig start up

Powerful server
with a set of VMs

Services VMs

Pool of development
materials and services

Free for
donating

Project
targeted

List of start up
projects

Exemplary Active

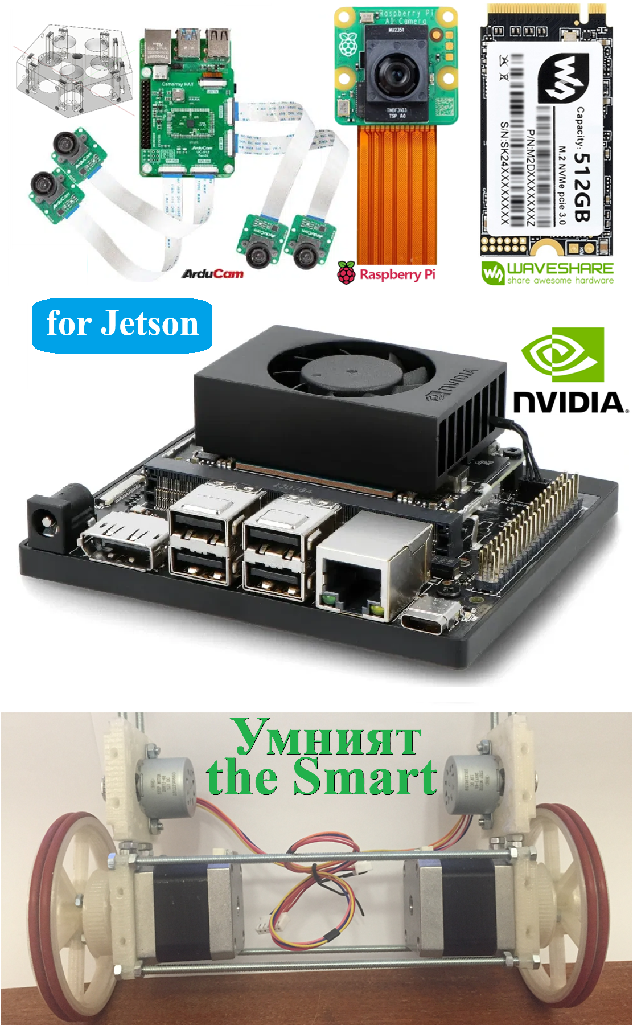
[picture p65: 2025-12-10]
assets/theSmart-06.png

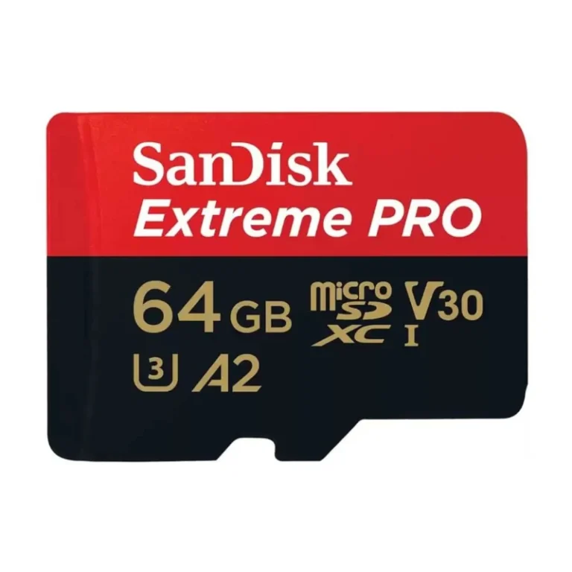
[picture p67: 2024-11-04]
assets/configs/sandisk-extreme-pro-64-768x768.webp

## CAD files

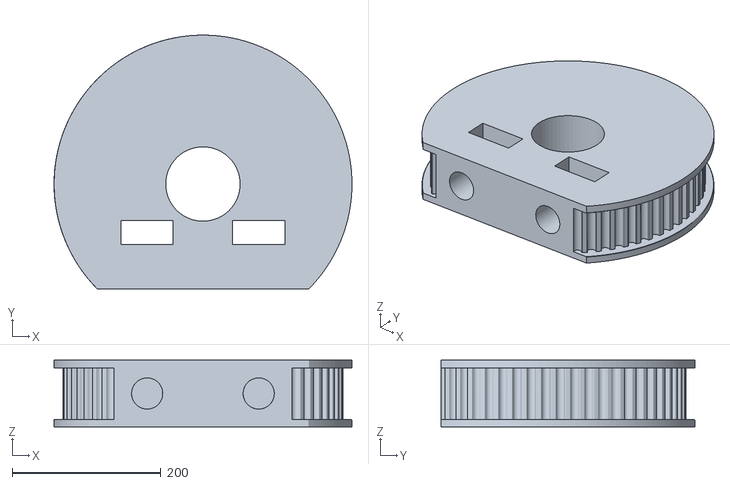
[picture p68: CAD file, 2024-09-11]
3dPrinting/GT2_60T_x10-g4 v1.stl
400.7 x 341.2 x 90.0

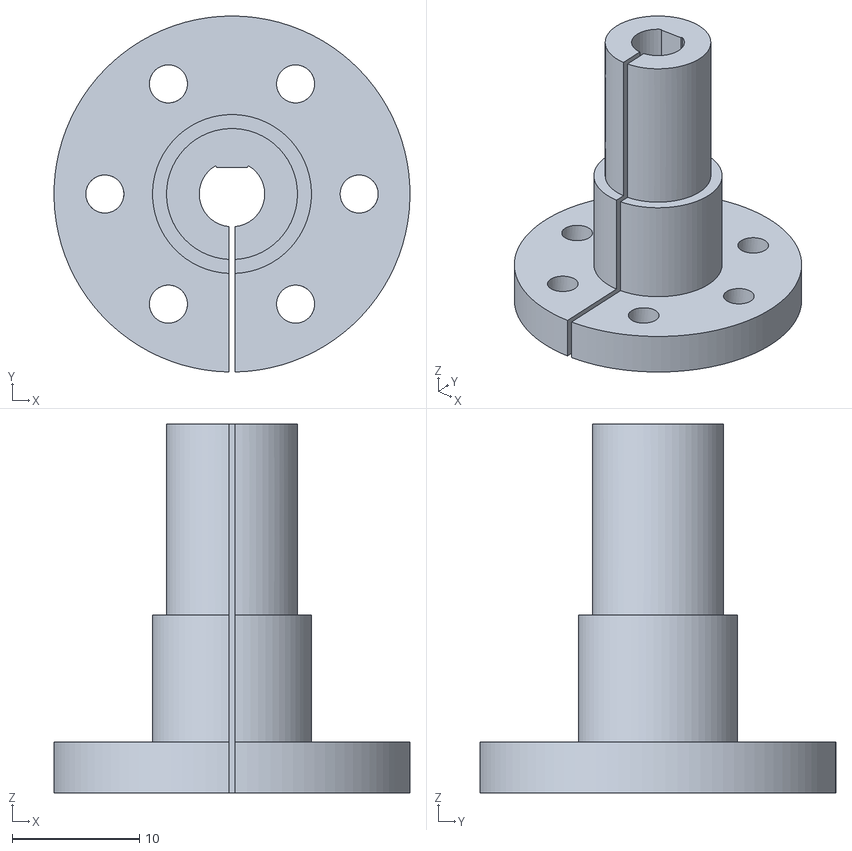
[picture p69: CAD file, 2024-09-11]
3dPrinting/Hub_12-10-D5_L20 v8.stl
28.0 x 28.0 x 29.0

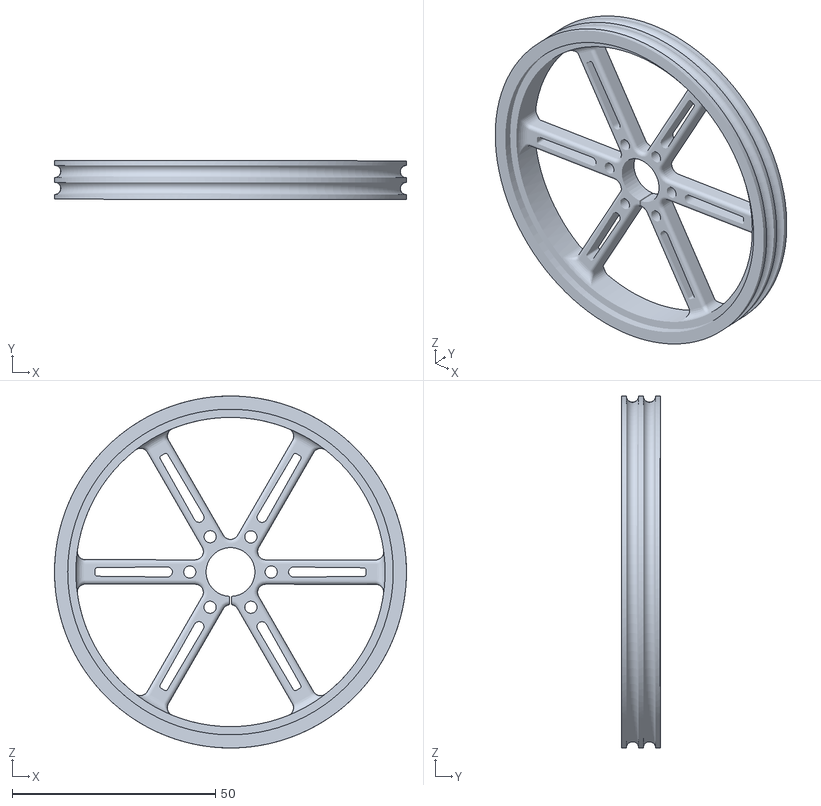
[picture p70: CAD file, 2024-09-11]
3dPrinting/Pololu90_Mod3_Shaft v1.stl
86.5 x 9.55 x 86.5

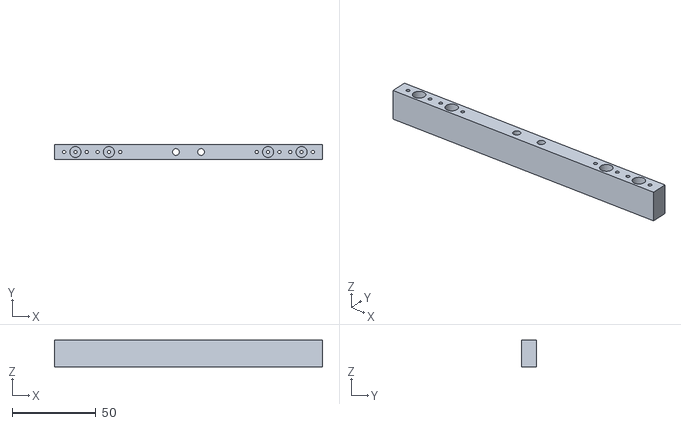
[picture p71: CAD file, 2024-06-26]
3dPrinting/LongArm-g3 v1.stl
160.0 x 9.00 x 16.0

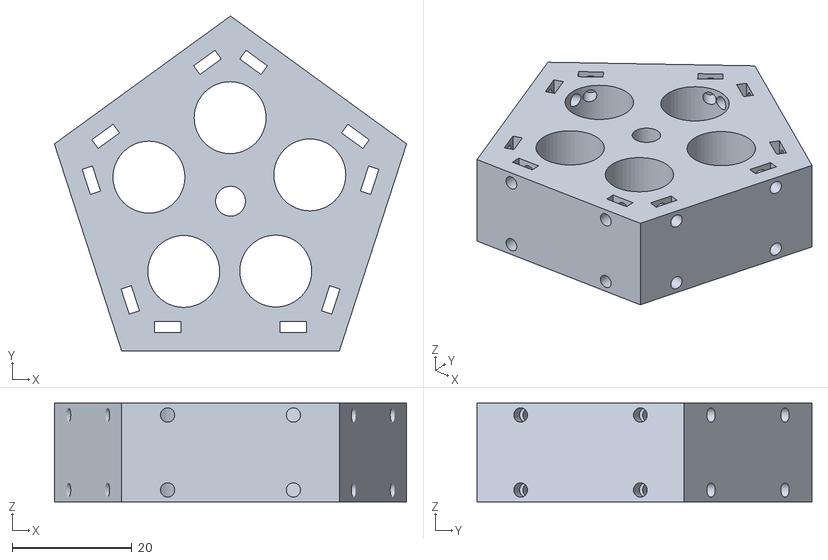
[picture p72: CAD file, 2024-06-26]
3dPrinting/Pentagram-g3 v1.stl
58.8 x 55.9 x 16.5

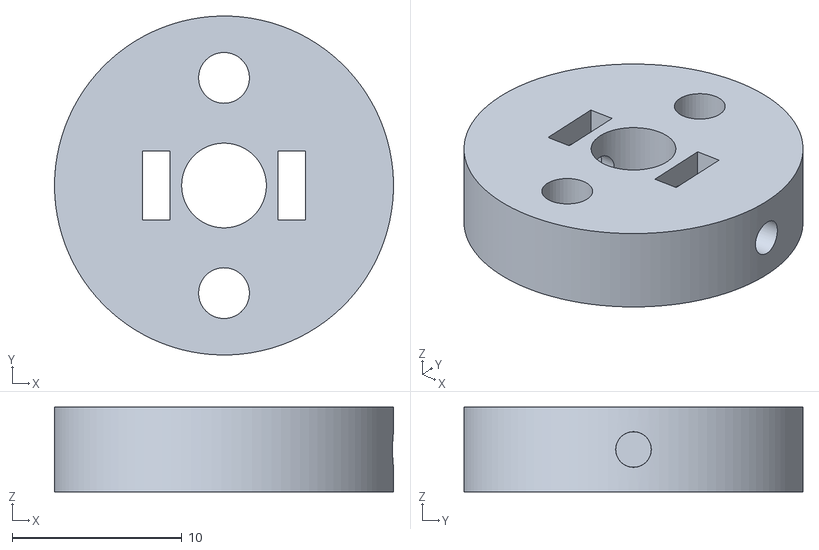
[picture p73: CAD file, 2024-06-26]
3dPrinting/WheelAdapter v7.stl
20.0 x 20.0 x 5.00

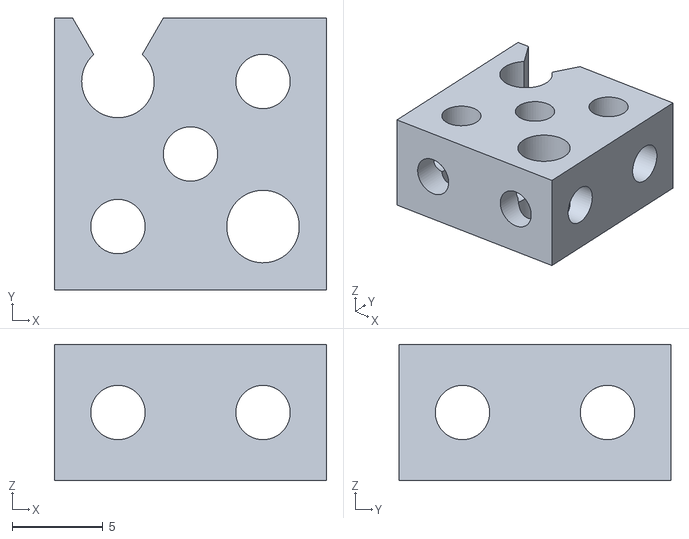
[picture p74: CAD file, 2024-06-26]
3dPrinting/UniCube-g3 v6.stl
15.0 x 15.0 x 7.50

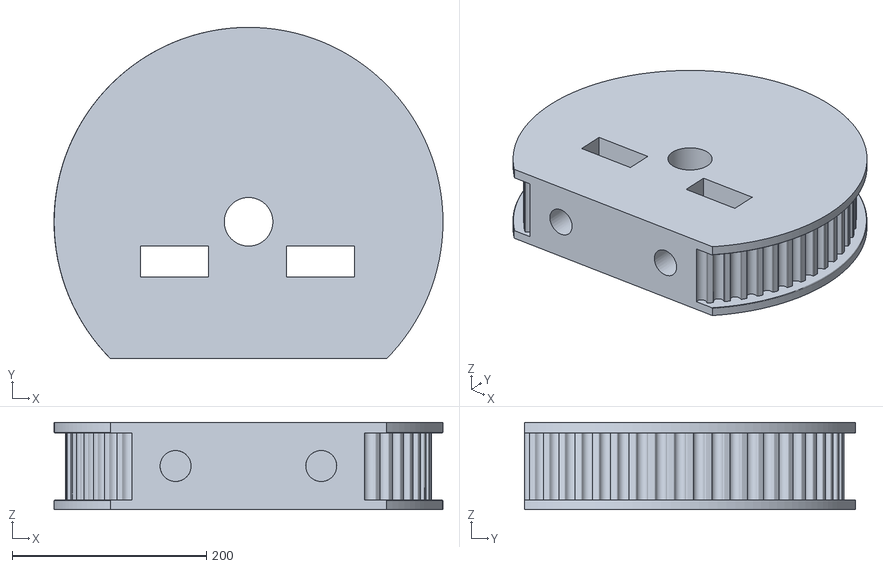
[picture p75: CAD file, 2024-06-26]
3dPrinting/GT2_60T_x10-g3 v1.stl
400.7 x 341.2 x 90.0

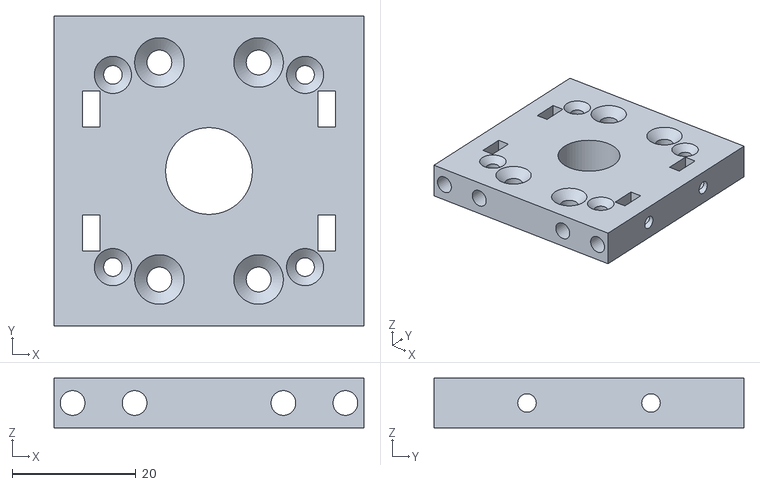
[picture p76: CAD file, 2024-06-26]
3dPrinting/SmallMotorMount-g3 v2.stl
50.0 x 50.0 x 8.00

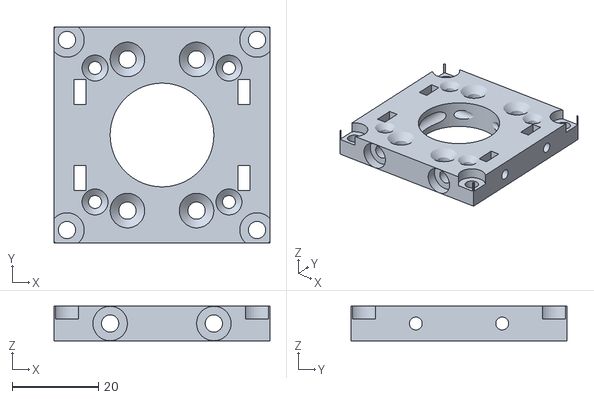
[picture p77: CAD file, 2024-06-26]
3dPrinting/MotorMount-g3 v6.stl
50.0 x 50.0 x 8.00

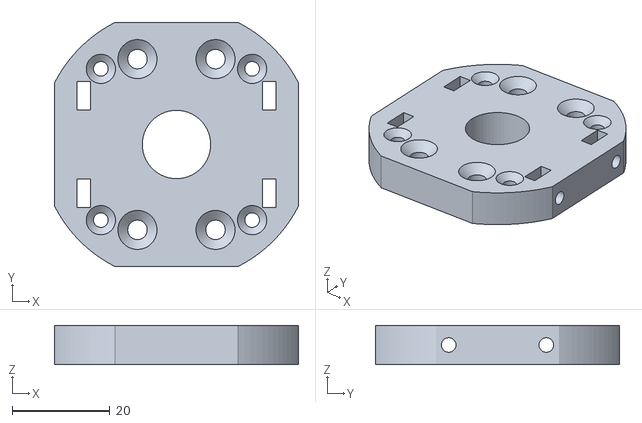
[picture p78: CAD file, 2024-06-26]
3dPrinting/CircularMotorMount-g3 v2.stl
50.0 x 50.0 x 8.00

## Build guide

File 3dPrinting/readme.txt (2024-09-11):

All STL files can be printed without modification except GT2_60T_*.stl which should be scaled down 10 times.
Some details like GT2_60T_*, LongArm_* and MotorMount_* could be printed with fill density down to 25%.
Some details like GT2_60T_*, Hub_* and Pololu90_* could be printed with lower velosity down to 25/10 mm/s
Test printing was done on Anycubic 3d printer with PLA filament at 50 mm/sec print speed and 210°C / 55°C.

stl/gcode - latest files changed and thier print conditions

Hub_12-10-D5_L20 v8    - 1pc, 210/55 deg, 10 mm/s, 100% - 1:29, 1.68 m,  5 g
Pololu90_Mod3_Shaft v1 - 1pc, 210/55 deg, 25 mm/s, 100% - 2:24, 6.26 m, 18 g (Rotate 90 deg)
GT2_60T_x10-g4 v1      - 1pc, 210/55 deg, 25 mm/s, 100% - 1:11, 3.25 m, 10 g (Scale 0.1)
GT2_60T_x10-g4 v1-F-25 - 1pc, 210/55 deg, 25 mm/s,  25% - 0:43, 1.83 m,  5 g (Scale 0.1)
MotorMount-g3 v6       - 1pc, 210/55 deg, 50 mm/s, 100% - 1:15, 5.41 m, 16 g
MotorMount-g3 v6-F-25  - 1pc, 210/55 deg, 50 mm/s,  25% - 0:51, 3.21 m, 9 g
LongArm-g3 v1          - 1pc, 210/55 deg, 50 mm/s, 100% - 1:44, 8.77 m, 26 g (Rotate 90 deg)
LongArm-g3 v1-F-25     - 1pc, 210/55 deg, 50 mm/s,  25% - 1:02, 4.54 m, 13 g (Rotate 90 deg)

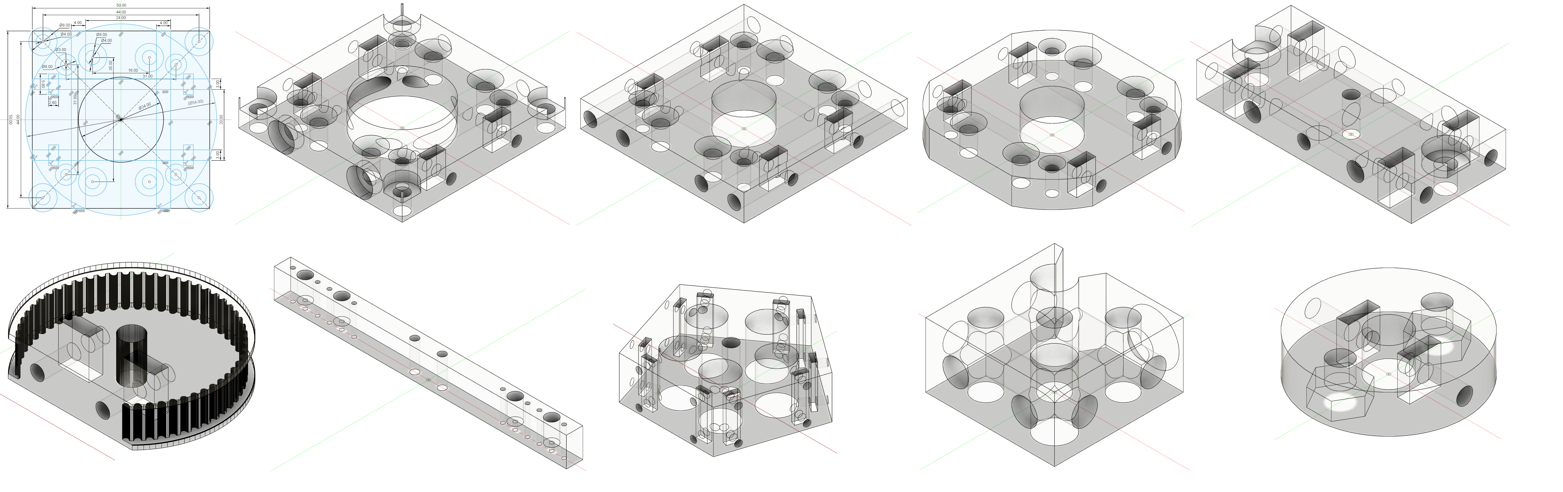
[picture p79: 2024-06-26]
assets/3D-Printing-Details.png

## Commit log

2025-12-08 Revise Raspberry Pi 5 section in README
    Updated images and descriptions for Raspberry Pi 5 accessories.
2025-12-08 Clarify camera connection options in README
2025-12-09 Update Jetson Orin Nano module description in README
2025-12-09 Update Raspberry Pi 5 specifications in README
2025-12-09 Update Jetson Orin Nano description in README
2025-12-10 Update power consumption details in README
2025-12-10 Update Nvidia Jetson (Orin) Nano description
2025-12-13 Update README with Raspberry Pi AI Kit usage details
    Added information about using Raspberry Pi AI Kit and AI Camera with Raspberry Pi 5, including performance tests and software details.
2025-12-14 Revise Raspberry Pi AI Kit and camera usage details
    Updated details about Raspberry Pi AI Kit usage, including performance metrics and camera specifications.
2025-12-14 Fix formatting in BOM and base features section
2025-12-15 Update README with video demonstrations and details
    Added videos demonstrating RPi Pico PIO algorithm and dual camera streaming server with ePTZ control.
2025-12-15 Update README with video links for RPi Pico projects
    Added links to videos demonstrating RPi Pico functionalities.
2025-12-15 Revise Raspberry Pi 5 AI Kit performance details
    Updated performance test results for Raspberry Pi 5 with HAILO 8L AI Kit, including improved Geekbench scores and additional details on software and hardware setup.
2025-12-15 Update camera options and descriptions in README
2025-12-15 Update Nvidia Jetson model references in README
2025-12-17 Update power consumption details and date
2026-01-13 Revise performance comparison details in README
    Updated the performance comparison section to clarify the tested AI solutions and added notes regarding PCIe Gen 3 switch benefits.
2026-01-16 Enhance README with motor comparison details
    Added detailed comparison of brushless direct drive PMSM servo motors, including specifications and features.
2026-01-16 Update motor comparison tables and images in README
2026-01-16 Update README with Direct Drive Servo Motors details
2026-01-19 Update Waveshare link in README for motors selection
